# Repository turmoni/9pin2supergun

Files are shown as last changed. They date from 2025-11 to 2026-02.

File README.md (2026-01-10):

# 9pin2supergun
A project to read a CD32, Mega Drive/Genesis, or generic 9-pin gamepad and output each control to a separate pin for use with Neo Geos and/or Superguns.

I am personally using this code with a [Monster Joysticks CD32 joystick](https://monsterjoysticks.com/deluxe-cd32-retro-joystick-kit-classic) and a [Minigun Supergun](https://www.arcade-projects.com/threads/minigun-supergun-an-open-source-supergun.9408/).

There is a chance that there will be USB host support in the future, if using [the PCB](pcb/).

## Hardware

There are two expected paths to getting the hardware needed to use this; either build the PCB, or hook up a Pi Pico. For the most compact setup, but needing some more moderate to advanced soldering skills, build the PCB. For a potentially easier build, hook up a Pi Pico.

The PCB's files and some basic instructions can be found in [the pcb directory](pcb/). This isn't for people who are new to soldering - it has surface mount components, a dense layout, and the RP2040 package is very fine pitched.

Schematics and a reference PCB for hooking up a Pi Pico, along with details about the parts used, can be found in [the pico_reference directory](pico_reference/).

## Installation

If you don't want to customise anything, grab the latest uf2 file from [the releases page](https://github.com/turmoni/9pin2supergun/releases/) that matches your setup and install it to your board by holding down BOOTSEL when plugging it in to a PC, and then copying the file on to the storage device that appears. The PCB's BOOTSEL button is at the top-right. The options are:

* 9pin2supergun-**pcb**-v\*.uf2 - if you're using [the PCB I designed](pcb/)
* 9pin2supergun-**pico**-v\*.uf2 - if you're wiring up a Pico as per the schematic

Don't worry if you're missing optional components, the code shouldn't care.

## Usage

Once you've got a board programmed, using it is pretty much a case of setting the switch to the right position, plugging it in, and going! If you've fitted the LED, it will tell you which mode you're in:
* Red: Amiga CD32 mode
* Blue: Mega Drive/generic mode
* Yellow: Mega Drive/generic mode with the buttons swapped

The button mapping is as follows:

| Output | CD32[^1]  | Mega Drive/Genesis (6- or 3-button) | Generic 9-pin |
| --- | ---  | --- | --- |
| Up | Up | Up | Up |
| Down | Down | Down | Down |
| Left | Left | Left | Left |
| Right  | Right | Right | Right |
| 1 | G | A | 1 |
| 2 | Y | B | 2 |
| 3 | LS | C | N/A |
| 4 | R | X | N/A |
| 5 | B | Y | N/A |
| 6 | RS | Z | N/A |
| Start  | Pause | Start | 1 + 2 |
| Coin | Pause + G | Mode | N/A |

Of course, X, Y, Z, and Mode aren't present on a 3-button Mega Drive controller, so these buttons aren't available there.

Since the Mega Drive layout may be the opposite of what's wanted, you can press and hold mode for three seconds to swap ABC and XYZ.

If you don't want the 1+2 mapping for generic 9-pin controllers, set `MAP_GENERIC_AB_TO_START` to false and rebuild the code. If you don't want the Pause + Green mapping for CD32 controllers, or want it to be a different button combination, change `CD32_COIN_BITMASK` (there are comments in the code to explain its format). Since these are pretty niche, I'm not sure figuring out a runtime configuration option is worth it.

## Building the code

This project is based on the [rp2040 project template](https://github.com/rp-rs/rp2040-project-template), have a look there for details. You need a `rust` build environment and the project will build with Cargo.

If you're using a Pi Pico, rather than the PCB, pass the `--features pi_pico` flag to `cargo` when building to get the right pin assignments.

## Anything else

This polls at 125Hz for the CD32 - I don't know whether a real CD32 pad will be happy with this, but I don't see why it wouldn't. The timing for each polling burst is based on what I observed with my PAL Amiga 500+, so that should be fine, but it was only polling at 50Hz. Given how little time is spent polling compared to waiting even at 125Hz, though, I can't imagine what issues might arise.

The Mega Drive controller support polls at around 140Hz.

Current draw seems fairly low, hovering at around 20-25mA on the controllers I've tested it with. If you're worried, power it up via USB (not whilst connected to a 15-pin port!) and use a USB power meter to see how much it's drawing.

## Credits

Thanks to [Mathew Carr's PSCD32 Development Diary](https://www.mrdictionary.net/PSCD32/diary/2019_08_09.htm) for documenting how the CD32 protocol actually works, and to [the RetroSix Wiki's Mega Drive controller page](https://www.retrosix.wiki/controller-interface-sega-mega-drive) for documenting the Mega Drive bits.

[^1]: Single-letter CD32 buttons refer to the colour, LB and RB are the shoulder buttons

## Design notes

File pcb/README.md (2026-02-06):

# 9pin2supergun PCB

This is a PCB that contains all the components needed for a fully-functional hardware adapter to work with the [9pin2supergun project](/) in a compact package.

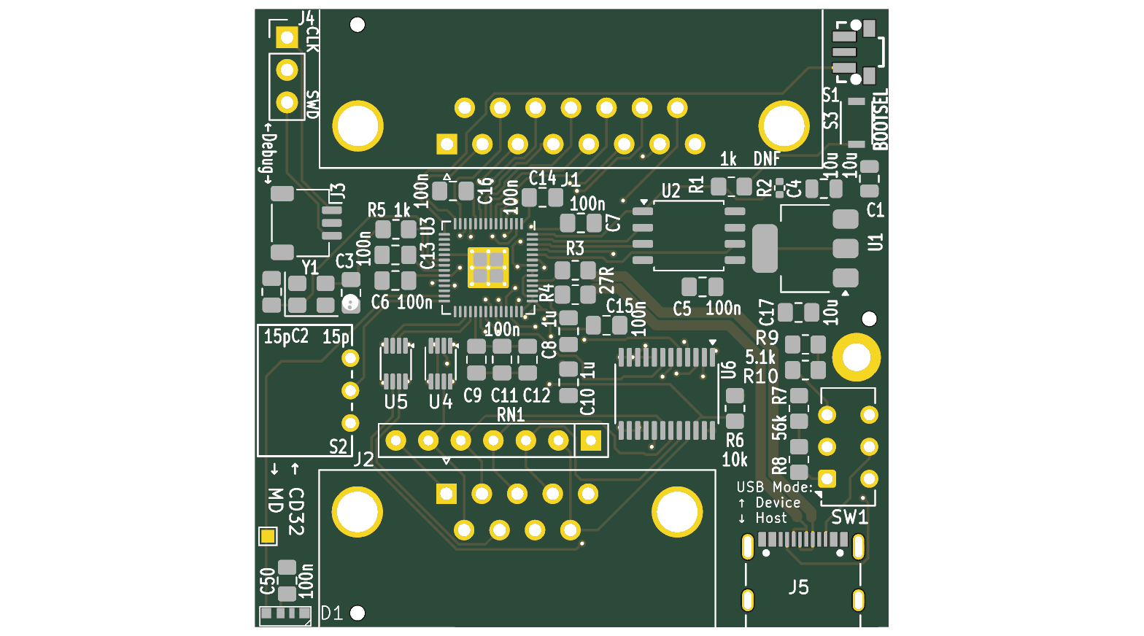
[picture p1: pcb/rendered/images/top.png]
The top of the PCB
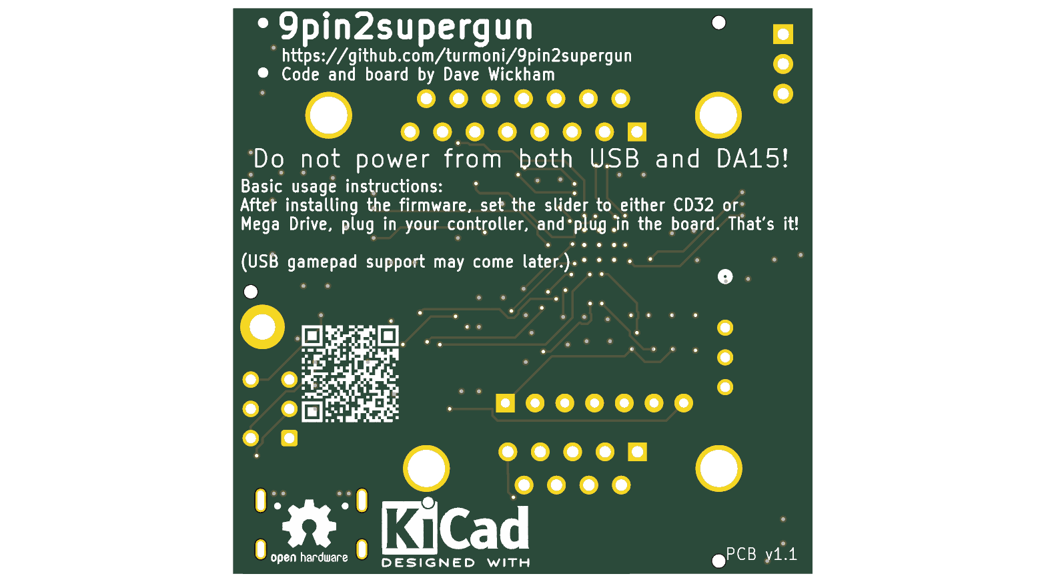
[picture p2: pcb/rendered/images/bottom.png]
The bottom of the PCB
 

## Building one

The KiCad project is in this directory, and for convenience each push gets rendered to [the `rendered` directory](/pcb/rendered/) as a PDF of the schematics, a set of gerber files, and a BOM as a CSV. You *should* be able to use [the gerber archive](/pcb/rendered/gbr.zip) to order boards directly, but for best results you should generate them yourself following your PCB fabricator's instructions (e.g. [for JLCPCB](https://jlcpcb.com/help/article/how-to-generate-gerber-and-drill-files-in-kicad-7)).

Unlike the related [Neo Geo Controller Tester](https://github.com/turmoni/neogeo_controller_tester), this is a moderately advanced soldering job. Don't be scared away from it if you're experienced with soldering (although you may need to learn some new techniques for fine pitched surface-mount components like the RP2040, and you probably want a hot plate, hot air gun, and solder paste), but if you're a complete beginner, this isn't for you.

The [BOM CSV](/pcb/rendered/bom.csv) has the list of parts, but I don't know how useful that is for importing elsewhere. I have [a DigiKey list](https://www.digikey.co.uk/en/mylists/list/U1CG00OTBV) that contains all the components that are needed, although at the time of writing, some of them are not available to order.

You may be able to get this fully/partially assembled from your PCB manufacturer - I didn't do this, so I can't comment, but there are only a few unusual components to manually spec and they are at least in LCSC (JLCPCB)'s database. If I end up doing this, I will probably replace U6 with more of the same type of shifter as U4 and U5 for cost reasons (one less reel to load).

When assembling, note that R2 is marked as DNF - if you're using the specified flash module, you shouldn't need to fit a resistor there. See [Hardware Design with RP2040](https://datasheets.raspberrypi.com/rp2040/hardware-design-with-rp2040.pdf) (PDF) for more information on this, since most of the support circuitry is adapted from that reference design.

## Things to note

SW1 switches between presenting itself as a USB device or a USB host, based on the resistors on the CC pins. This doesn't change anything with the software, and any cables other than Type C to Type C will be entirely unimpacted by this. Set it to Device (up) if you want to plug it into your PC, and Host (down) if you want to plug a gamepad into it. Since there's no code at the moment that uses host mode, it's safe to leave or hardcode it as a device for the moment (connect the middle pins of the switch to their respective top pins, and populate R9 and R10).

Do not power the board from more than one place, e.g. don't plug it into a supergun *and* a USB power source.

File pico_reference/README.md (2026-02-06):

# 9pin2supergun Reference Pico Design

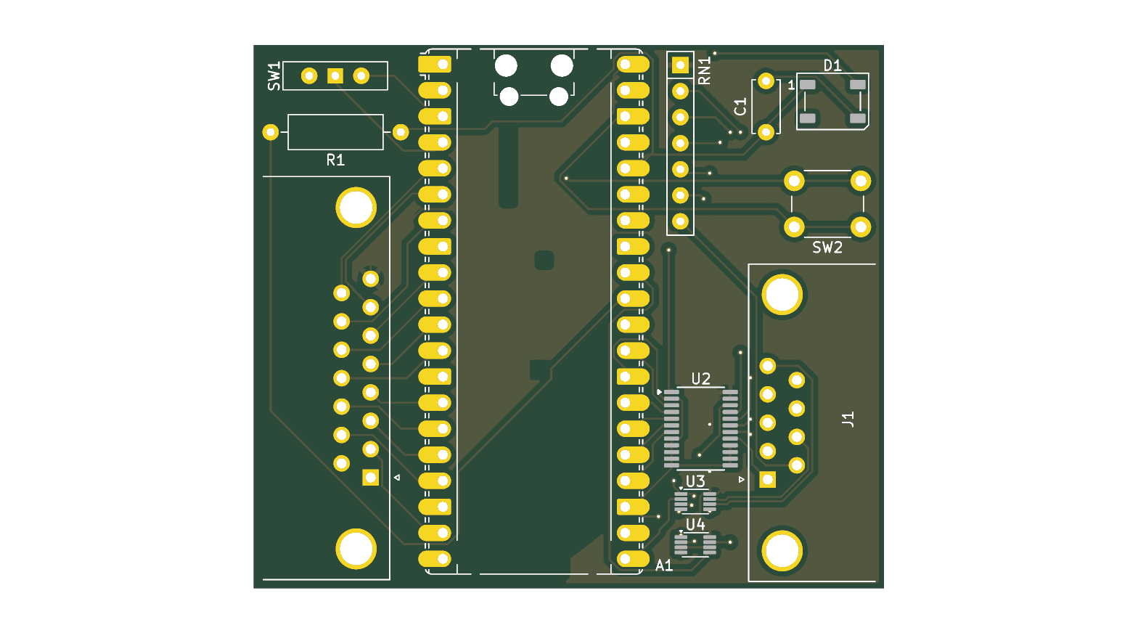
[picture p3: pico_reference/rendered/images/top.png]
The top of the reference PCB


This is a KiCad project for hooking up a Pi Pico to the appropriate hardware to get a fully working setup. As I see it, there are three main purposes for this project:

* To provide the schematic to use if wiring one up by hand, e.g. on a breadboard
* To give me PCBs based on the schematic so I can test that the schematic I've provided actually works, and is what the code expects
* To give a foundation for making new PCBs with different hardware than what I happened to have on hand

# Using the schematic

The schematic is hopefully fairly simple to understand, and can be found either by opening this project up in KiCad, or by looking at [the rendered PDF](rendered/sch.pdf).

# Building a PCB

First up: you probably don't want to use the PCB I've designed. The layout was literally done in about 20 minutes, with very little care given to routing traces to be neat, and it's designed to use the hardware I had on hand. If you want to use the components I've specified, I recommend instead using [the main PCB](../pcb), which is more compact and not *that* much harder to solder than what I have here.

If you do want to modify it, the KiCad project is in this directory.

For convenience each push gets rendered to [the `rendered` directory](rendered/) as a PDF of the schematics, a set of gerber files, and a BOM as a CSV, but again, you probably don't want to use the generated fabrication files as-is.

# Components and their explanations

If you're going to use your own components, the key things are:
 * U2 ([SN74LVC8T245](https://www.ti.com/product/SN74LVC8T245)) - this is just level shifting the input from the controller down to 3.3V. If you want to try out the Pico's 5V tolerance, you can omit this and RN1 if you want. Often the inputs will be either floating or GND, and so safe anyway, but I wouldn't totally rely on this being the case
 * U3/U4 ([SN74LVC2T45DCUR](https://www.ti.com/product/SN74LVC2T45)) - two-bit level shifters. U3 handles those that are always outputs, and U4 handles pin 6, which can either be an input or an output.
 * RN1 (10k resistor network) - pulling up the inputs from the controller port. Omit it if you're also omitting the level shifters
 * SW1 (SPDT switch) - the mode switch. Switches between Mega Drive (floating) and CD32 (tied to GND) modes. You can hardcode this if you're only using one type of controller
 * SW2 (standard push button) - not actually used, but might be helpful in the future
 * D1 (WS2812B LED) - indicates what mode you're in (including if the button rows are flipped in Mega Drive mode). Omit this if you don't care.

## More on level shifting

To recap, the level shifter U2 handles those inputs that are only ever inputs (pulled up to 5V). U3 handles both of the two outputs that can also be the +5V supply. U4 handles the one remaining pin that's either an input or an output depending on whether it's in CD32 or Mega Drive mode. There is nothing particularly special about any of these, they're just directional level shifters that can handle translating 3.3V to 5V or vice versa.
 
The connections to the DE9 connector are as follows:

| Pin | CD32 Function | CD32 Direction | Mega Drive Function | MD Direction |
| --- | --- | --- | --- | --- |
| 1 | Up | In | Up/Z | In |
| 2 | Down | In | Down/Y | In |
| 3 | Left | In | Left/X/GND | In |
| 4 | Right | In | Right/Mode/GND | In |
| 5 | Latch | Out | +5V | Out |
| 6 | Fire 1/Clock  | Out | B/A | In |
| 7 | +5V | Out | Select | Out |
| 8 | GND | N/A | GND | N/A |
| 9 | Fire 2/Data | In | C/Start | In |

As the table shows, the DE9 connector is a lot simpler if you're only targetting a single platform; for a CD32, you can permanently wire pin 7 to +5V, and pin 6 as an output, whereas with a Mega Drive controller you can wire pin 5 to +5V and pin 6 as an input. You may also be able to get away with not needing level shifters in this case, if you're willing to risk +5V into your Pico's GPIO pins, and your controller recognises 3.3V logic levels.

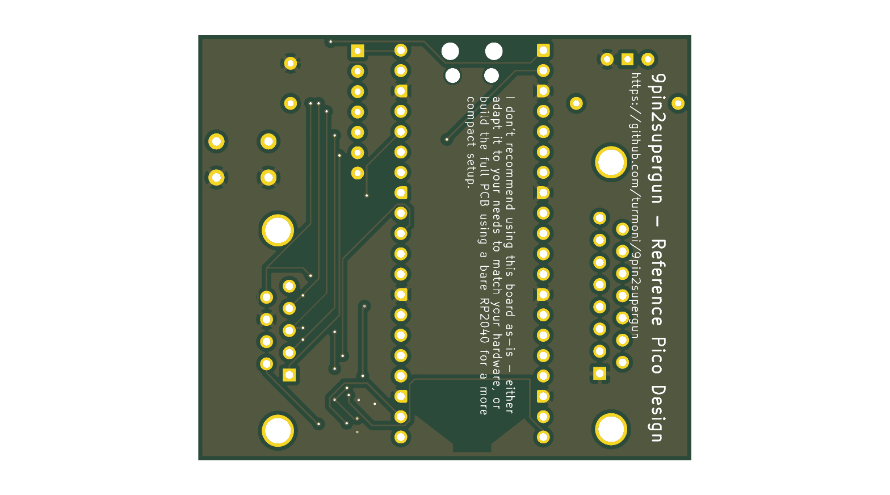
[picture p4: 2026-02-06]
pico_reference/rendered/images/bottom.png

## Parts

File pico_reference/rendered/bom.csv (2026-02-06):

Refs | Value | Footprint | Qty | DNP
A1 | RaspberryPi_Pico | Module:RaspberryPi_Pico_Common_Unspecified | 1
C1 | 100n | Capacitor_THT:C_Disc_D5.0mm_W2.5mm_P5.00mm | 1
D1 | WS2812B | LED_SMD:LED_WS2812B_PLCC4_5.0x5.0mm_P3.2mm | 1
J1 | Controller Input | Connector_Dsub:DSUB-9_Pins_Horizontal_P2.77x2.84mm_EdgePinOffset7.70mm_Housed_MountingHolesOffset9.12mm | 1
J2 | Output | Connector_Dsub:DSUB-15_Socket_Horizontal_P2.77x2.84mm_EdgePinOffset7.70mm_Housed_MountingHolesOffset9.12mm | 1
R1 | 10k | Resistor_THT:R_Axial_DIN0309_L9.0mm_D3.2mm_P12.70mm_Horizontal | 1
RN1 | R_Network06 | Resistor_THT:R_Array_SIP7 | 1
SW1 | SW_Wuerth_450301014042 | Button_Switch_THT:SW_Slide-03_Wuerth-WS-SLTV_10x2.5x6.4_P2.54mm | 1
SW2 | SW_Push | Button_Switch_THT:SW_PUSH_6mm | 1
U2 | SN74LVC8T245 | Package_SO:TSSOP-24_4.4x7.8mm_P0.65mm | 1
U3 | SN74LVC2T45DCUR | Package_SO:VSSOP-8_2.3x2mm_P0.5mm | 1
U4 | SN74LVC2T45DCUR | Package_SO:VSSOP-8_2.3x2mm_P0.5mm | 1

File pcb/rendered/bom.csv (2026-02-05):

Refs | Value | Footprint | Qty | DNP
C1 | 10u | Capacitor_SMD:C_0805_2012Metric | 1
C2 | 15p | Capacitor_SMD:C_0805_2012Metric_Pad1.18x1.45mm_HandSolder | 1
C3 | 15p | Capacitor_SMD:C_0805_2012Metric_Pad1.18x1.45mm_HandSolder | 1
C4 | 10u | Capacitor_SMD:C_0805_2012Metric | 1
C5 | 100n | Capacitor_SMD:C_0805_2012Metric_Pad1.18x1.45mm_HandSolder | 1
C6 | 100n | Capacitor_SMD:C_0805_2012Metric_Pad1.18x1.45mm_HandSolder | 1
C7 | 100n | Capacitor_SMD:C_0805_2012Metric_Pad1.18x1.45mm_HandSolder | 1
C8 | 1u | Capacitor_SMD:C_0805_2012Metric_Pad1.18x1.45mm_HandSolder | 1
C9 | 100n | Capacitor_SMD:C_0805_2012Metric_Pad1.18x1.45mm_HandSolder | 1
C10 | 1u | Capacitor_SMD:C_0805_2012Metric_Pad1.18x1.45mm_HandSolder | 1
C11 | 100n | Capacitor_SMD:C_0805_2012Metric_Pad1.18x1.45mm_HandSolder | 1
C12 | 100n | Capacitor_SMD:C_0805_2012Metric_Pad1.18x1.45mm_HandSolder | 1
C13 | 100n | Capacitor_SMD:C_0805_2012Metric_Pad1.18x1.45mm_HandSolder | 1
C14 | 100n | Capacitor_SMD:C_0805_2012Metric_Pad1.18x1.45mm_HandSolder | 1
C15 | 100n | Capacitor_SMD:C_0805_2012Metric_Pad1.18x1.45mm_HandSolder | 1
C16 | 100n | Capacitor_SMD:C_0805_2012Metric_Pad1.18x1.45mm_HandSolder | 1
C17 | 10u | Capacitor_SMD:C_0805_2012Metric_Pad1.18x1.45mm_HandSolder | 1
C50 | 100n | Capacitor_SMD:C_0805_2012Metric_Pad1.18x1.45mm_HandSolder | 1
D1 | SK6812B | 9pin2supergun:SK6812B | 1
J1 | Controller Output | Connector_Dsub:DSUB-15_Socket_Horizontal_P2.77x2.84mm_EdgePinOffset7.70mm_Housed_MountingHolesOffset9.12mm | 1
J2 | Controller Input | Connector_Dsub:DSUB-9_Pins_Horizontal_P2.77x2.84mm_EdgePinOffset7.70mm_Housed_MountingHolesOffset9.12mm | 1
J3 | Debug (JST SH) | Connector_JST:JST_SH_SM03B-SRSS-TB_1x03-1MP_P1.00mm_Horizontal | 1
J4 | Debug (2.54mm holes) | Connector_PinHeader_2.54mm:PinHeader_1x03_P2.54mm_Vertical | 1
J5 | UJ20-C-H-C-4-SMT-TR | 9pin2supergun:CUI_UJ20-C-H-C-4-SMT-TR | 1
R1 | 1k | Resistor_SMD:R_0805_2012Metric_Pad1.20x1.40mm_HandSolder | 1
R2 | DNF | Resistor_SMD:R_0402_1005Metric | 1
R3 | 27R | Resistor_SMD:R_0805_2012Metric_Pad1.20x1.40mm_HandSolder | 1
R4 | 27R | Resistor_SMD:R_0805_2012Metric_Pad1.20x1.40mm_HandSolder | 1
R5 | 1k | Resistor_SMD:R_0805_2012Metric_Pad1.20x1.40mm_HandSolder | 1
R6 | 10k | Resistor_SMD:R_0805_2012Metric_Pad1.20x1.40mm_HandSolder | 1
R7 | 56k | Resistor_SMD:R_0805_2012Metric_Pad1.20x1.40mm_HandSolder | 1
R8 | 56k | Resistor_SMD:R_0805_2012Metric_Pad1.20x1.40mm_HandSolder | 1
R9 | 5.1k | Resistor_SMD:R_0805_2012Metric_Pad1.20x1.40mm_HandSolder | 1
R10 | 5.1k | Resistor_SMD:R_0805_2012Metric_Pad1.20x1.40mm_HandSolder | 1
RN1 | 10k | Resistor_THT:R_Array_SIP7 | 1
S1 | 436333033816 | 9pin2supergun:436333033816 | 1
S2 | 09.10201.02 | footprints:SW3_09.10201.02_EAO | 1
S3 | R-667995 | 9pin2supergun:R-667995_MIT | 1
SW1 | SW_DPDT_x2 | Button_Switch_THT:SW_CK_JS202011CQN_DPDT_Straight | 1
U1 | NCP1117-3.3_SOT223 | Package_TO_SOT_SMD:SOT-223-3_TabPin2 | 1
U2 | W25Q128JVS | Package_SO:SOIC-8_5.23x5.23mm_P1.27mm | 1
U3 | RP2040 | MCU_RaspberryPi_and_Boards:RP2040-QFN-56 | 1
U4 | SN74LVC2T45DCUR | Package_SO:VSSOP-8_2.3x2mm_P0.5mm | 1
U5 | SN74LVC2T45DCUR | Package_SO:VSSOP-8_2.3x2mm_P0.5mm | 1
U6 | SN74LVC8T245 | Package_SO:TSSOP-24_4.4x7.8mm_P0.65mm | 1
Y1 | ABM8-272-T3 | Crystal:Crystal_SMD_3225-4Pin_3.2x2.5mm | 1

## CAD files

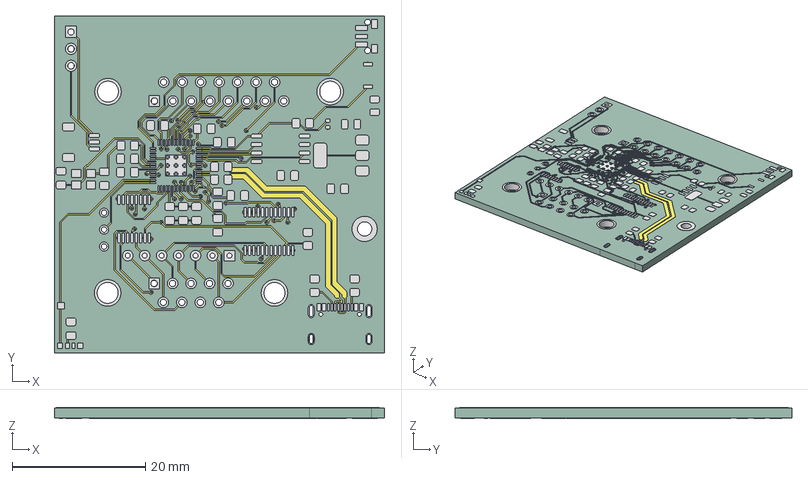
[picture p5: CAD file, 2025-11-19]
pcb/rendered/pcb.step
49.5 x 50.5 x 1.59 mm
9pin2supergun_copper
9pin2supergun_pad
9pin2supergun_via
9pin2supergun_PCB

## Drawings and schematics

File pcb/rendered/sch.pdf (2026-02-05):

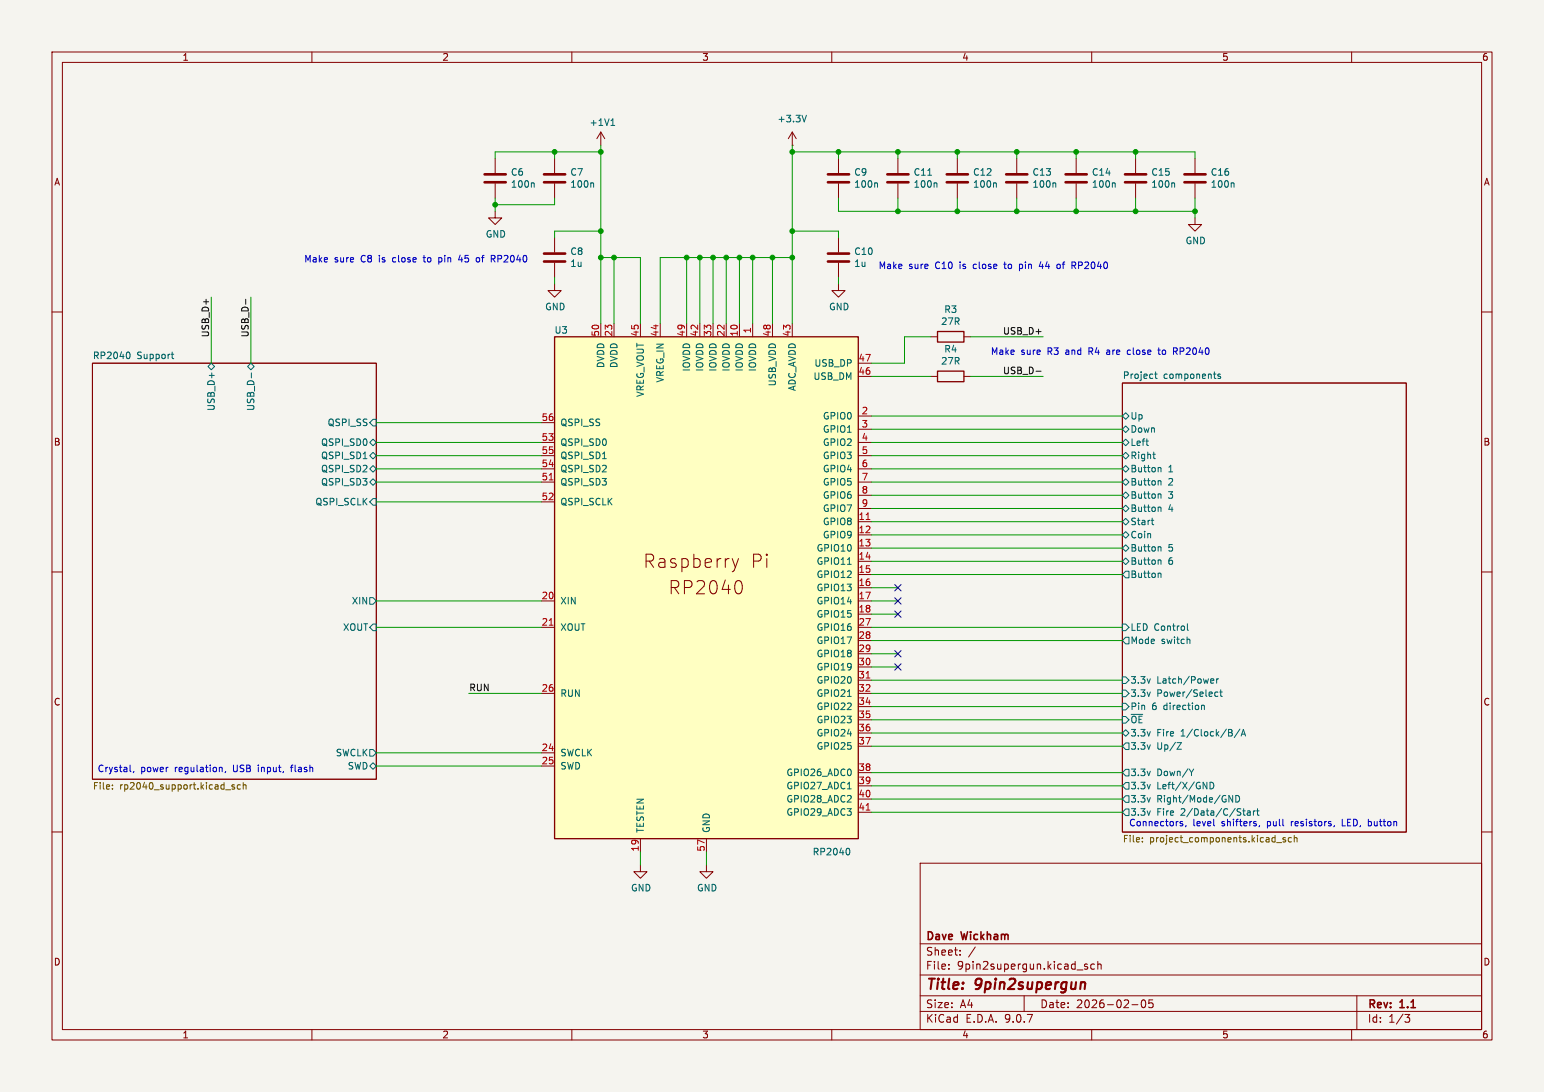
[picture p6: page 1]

LED Control Left Mode switch Pin 6 direction Right Start Up
3.3v Up/Z Button Button 1 Button 2 Button 3 Button 4 Button 5 Button 6 Coin Down

Project components File: project_components.kicad_sch SWCLK

3.3v Fire 2/Data/C/Start 3.3v Latch/Power 3.3v Left/X/GND
3.3v Power/Select 3.3v Right/Mode/GND

File: 9pin2supergun.kicad_sch Sheet: / Dave Wickham

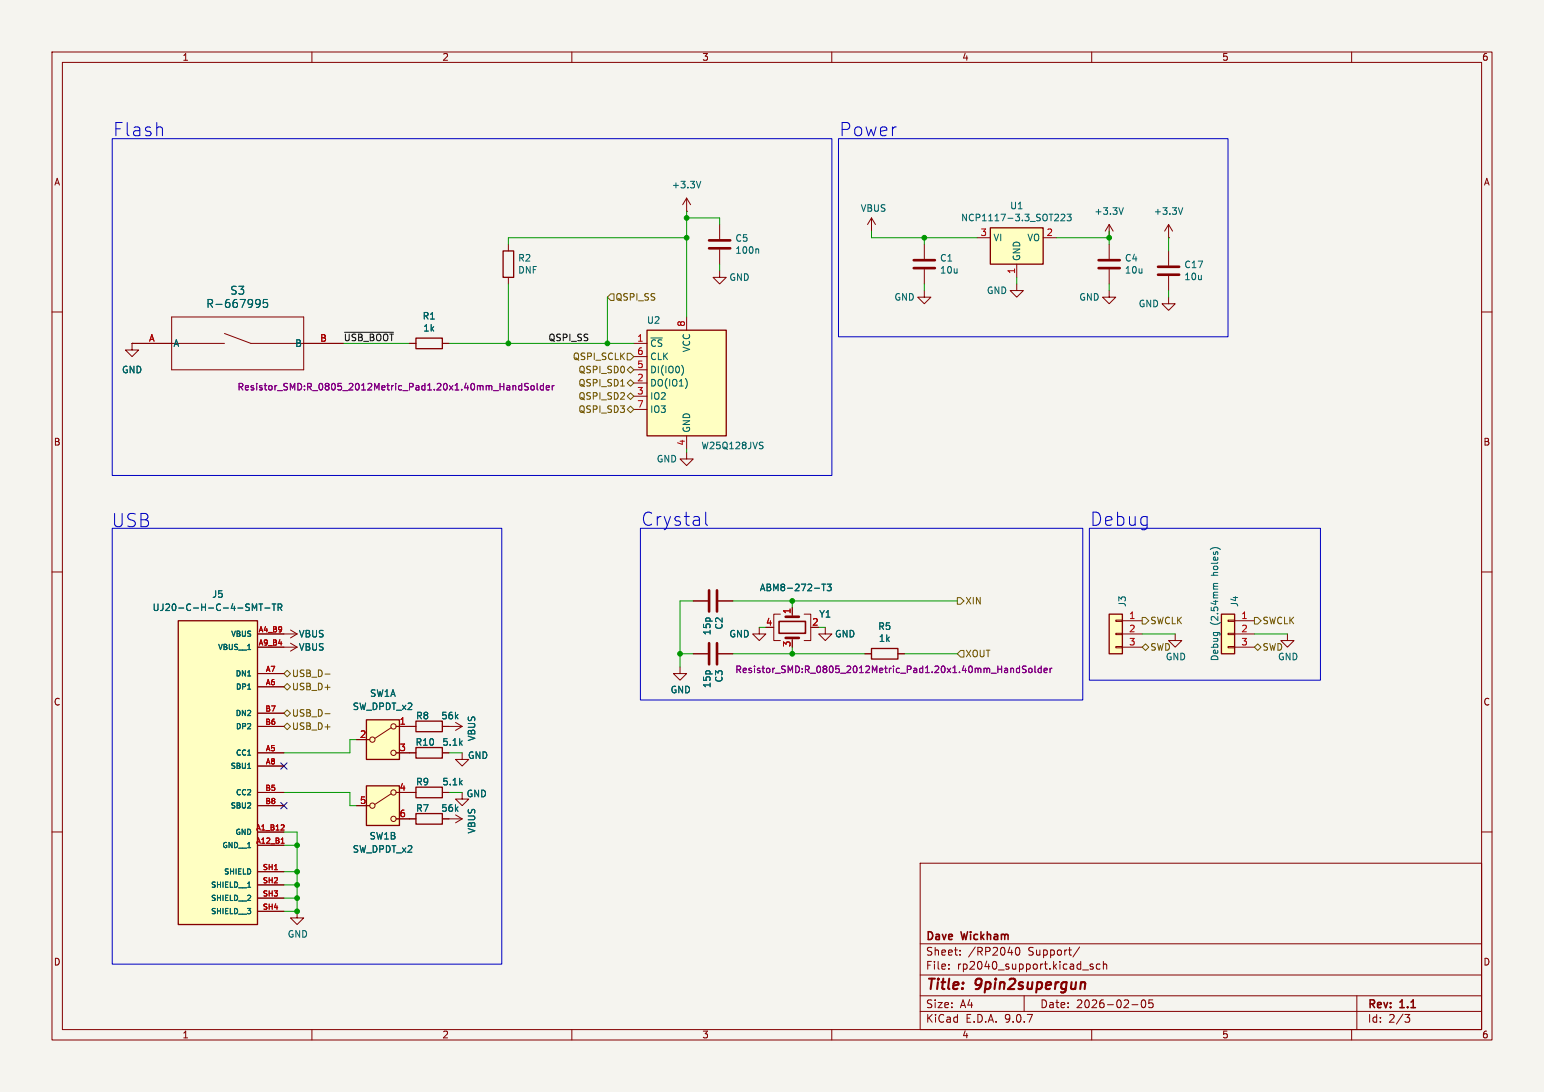
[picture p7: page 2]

~{CS} 1 CLK 6 DI(IO0) 5 DO(IO1) 2

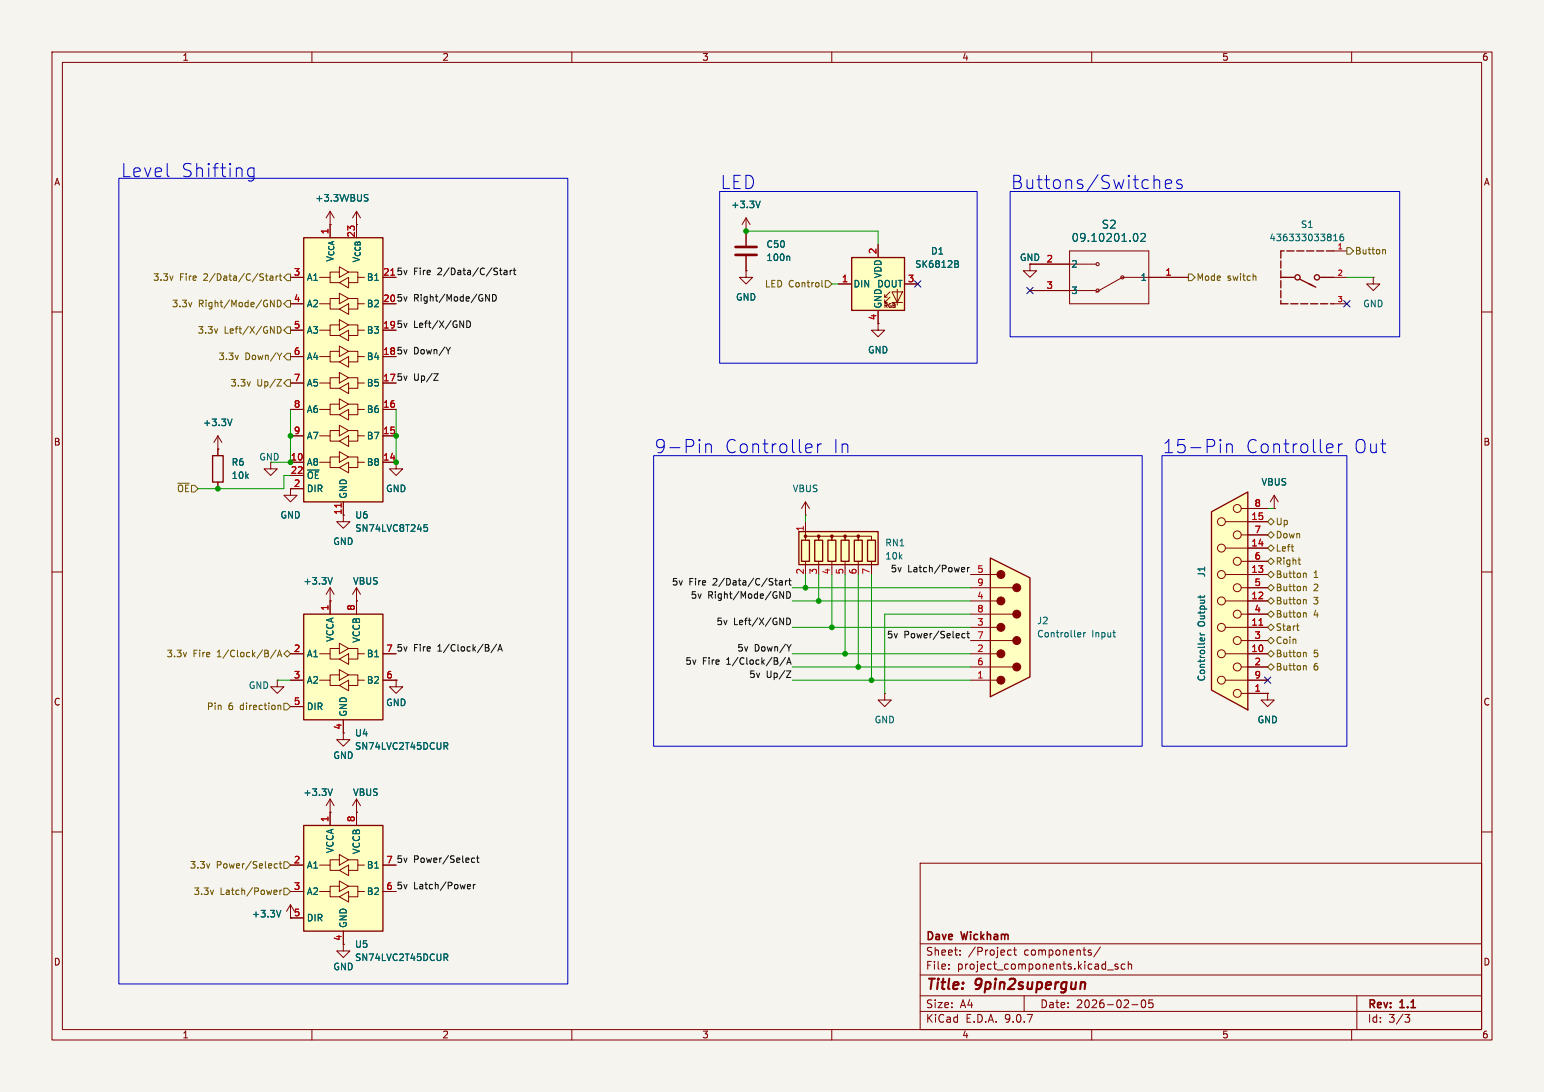
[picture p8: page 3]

Buttons/Switches Level Shifting
+3.3V VBUS GND
3.3v Fire 2/Data/C/Start 3.3v Up/Z Pin 6 direction

4 DOUT 3 D1 SK6812B GND GND GND

5v Fire 2/Data/C/Start 5v Down/Y

Left Mode switch LED Control

5v Latch/Power 5v Fire 1/Clock/B/A

5v Right/Mode/GND

5v Power/Select 5v Latch/Power

3.3v Latch/Power 3.3v Power/Select

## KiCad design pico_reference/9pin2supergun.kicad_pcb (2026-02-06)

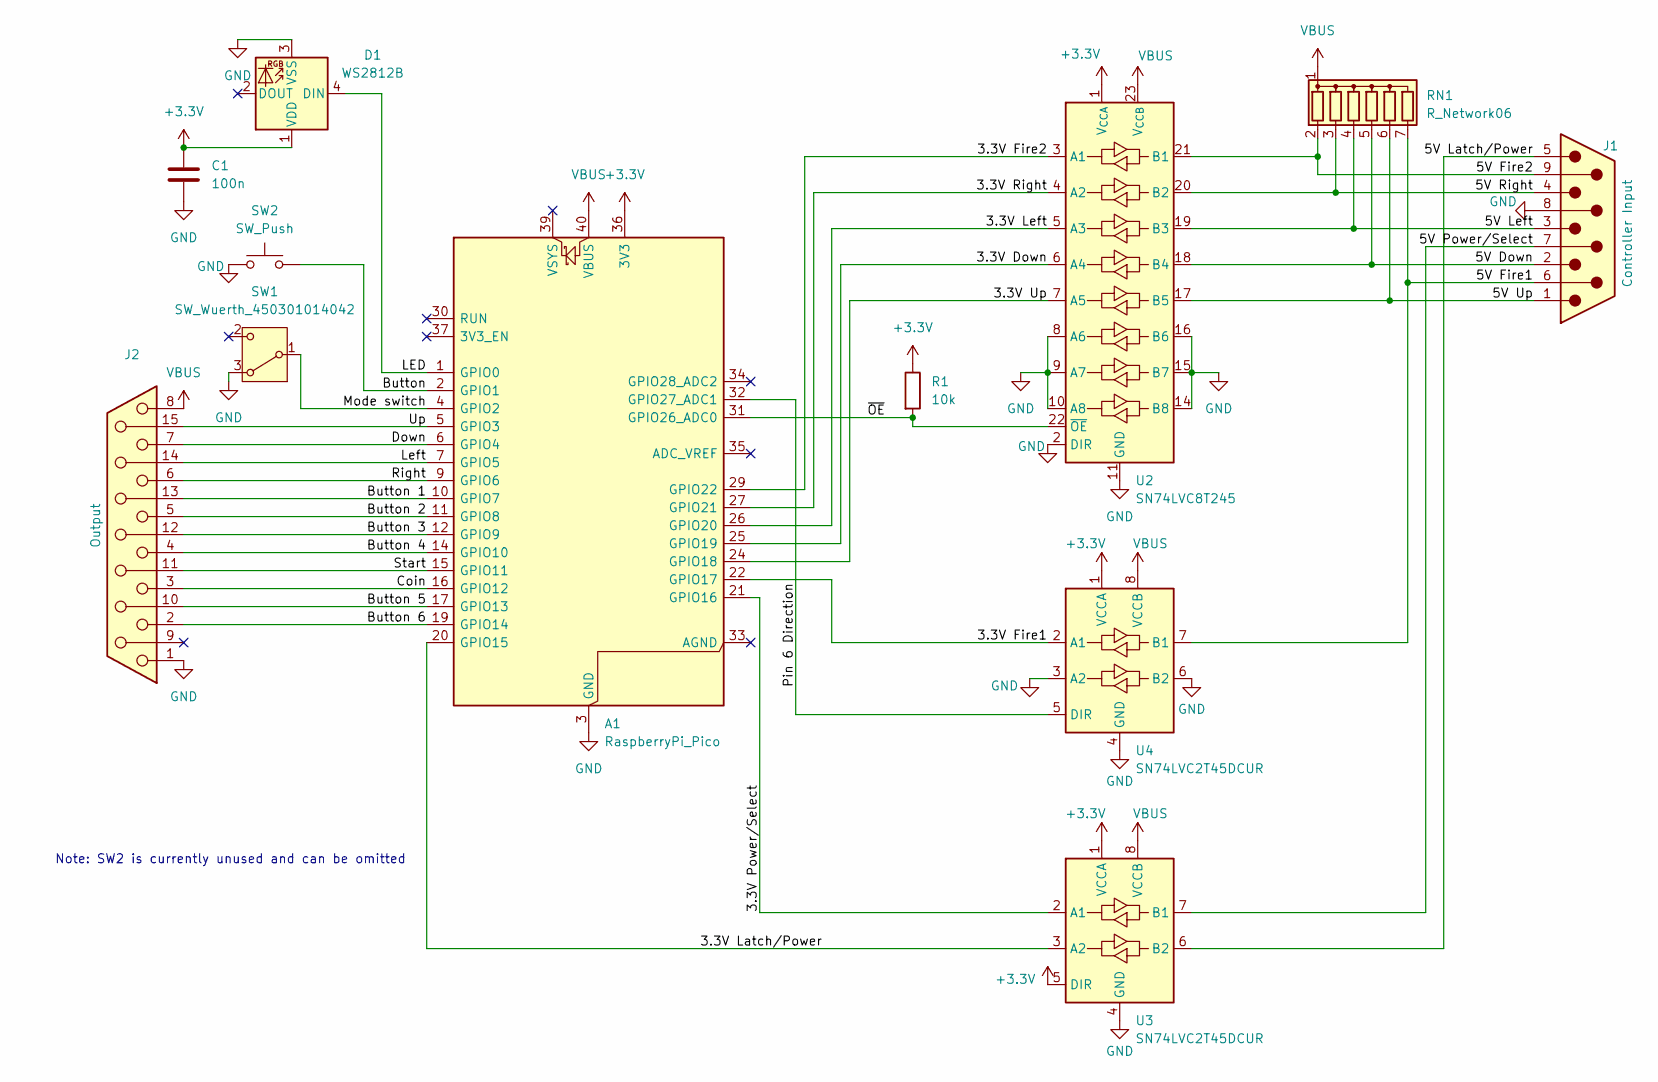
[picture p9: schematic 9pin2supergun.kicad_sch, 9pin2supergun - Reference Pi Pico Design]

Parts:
A1: RaspberryPi_Pico; RaspberryPi_Pico_Common_Unspecified
C1: 100n; C_Disc_D5.0mm_W2.5mm_P5.00mm
D1: WS2812B; LED_WS2812B_PLCC4_5.0x5.0mm_P3.2mm
J1: Controller Input; DSUB-9_Pins_Horizontal_P2.77x2.84mm_EdgePinOffset7.70mm_Hou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
J2: Output; DSUB-15_Socket_Horizontal_P2.77x2.84mm_EdgePinOffset7.70mm_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
R1: 10k; R_Axial_DIN0309_L9.0mm_D3.2mm_P12.70mm_Horizontal
RN1: R_Network06; R_Array_SIP7
SW1: SW_Wuerth_450301014042; SW_Slide-03_Wuerth-WS-SLTV_10x2.5x6.4_P2.54mm
SW2: SW_Push; SW_PUSH_6mm
U2: SN74LVC8T245; TSSOP-24_4.4x7.8mm_P0.65mm
U3, U4: SN74LVC2T45DCUR; VSSOP-8_2.3x2mm_P0.5mm

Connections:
+3.3V: A1.36 (3V3), C1.1, D1.1 (VDD), R1.1, U2.1 (V_{CCA}), U3.1 (VCCA), U3.5 (DIR), U4.1 (VCCA)
/3.3V Down: A1.25 (GPIO19), U2.6 (A4)
/3.3V Fire1: A1.22 (GPIO17), U4.2 (A1)
/3.3V Fire2: A1.29 (GPIO22), U2.3 (A1)
/3.3V Latch/Power: A1.20 (GPIO15), U3.3 (A2)
/3.3V Left: A1.26 (GPIO20), U2.5 (A3)
/3.3V Power/Select: A1.21 (GPIO16), U3.2 (A1)
/3.3V Right: A1.27 (GPIO21), U2.4 (A2)
/3.3V Up: A1.24 (GPIO18), U2.7 (A5)
/5V Down: J1.2, RN1.5 (R4), U2.18 (B4)
/5V Fire1: J1.6, RN1.7 (R6), U4.7 (B1)
/5V Fire2: J1.9, RN1.2 (R1), U2.21 (B1)
/5V Latch/Power: J1.5, U3.6 (B2)
/5V Left: J1.3, RN1.4 (R3), U2.19 (B3)
/5V Power/Select: J1.7, U3.7 (B1)
/5V Right: J1.4, RN1.3 (R2), U2.20 (B2)
/5V Up: J1.1, RN1.6 (R5), U2.17 (B5)
/Button: A1.2 (GPIO1), SW2.2
/Button 1: A1.10 (GPIO7), J2.13
/Button 2: A1.11 (GPIO8), J2.5
/Button 3: A1.12 (GPIO9), J2.12
/Button 4: A1.14 (GPIO10), J2.4
/Button 5: A1.17 (GPIO13), J2.10
/Button 6: A1.19 (GPIO14), J2.2
/Coin: A1.16 (GPIO12), J2.3
/Down: A1.6 (GPIO4), J2.7
/LED: A1.1 (GPIO0), D1.4 (DIN)
/Left: A1.7 (GPIO5), J2.14
/Mode switch: A1.4 (GPIO2), SW1.1 (B)
/Pin 6 Direction: A1.32 (GPIO27_ADC1), U4.5 (DIR)
/Right: A1.9 (GPIO6), J2.6
/Start: A1.15 (GPIO11), J2.11 (P111)
/Up: A1.5 (GPIO3), J2.15
/~OE: A1.31 (GPIO26_ADC0), R1.2, U2.22 (~OE)
GND: A1.3 (GND), A1.8 (GND), A1.13 (GND), A1.18 (GND), A1.23 (GND), A1.28 (GND), A1.38 (GND), C1.2, D1.3 (VSS), J1.8, J2.1, SW1.3 (A), SW2.1, U2.2 (DIR), U2.8 (A6), U2.9 (A7), U2.10 (A8), U2.11 (GND), U2.12 (GND), U2.13 (GND), U2.14 (B8), U2.15 (B7), U2.16 (B6), U3.4 (GND), U4.3 (A2), U4.4 (GND), U4.6 (B2)
VBUS: A1.40 (VBUS), J2.8, RN1.1 (common), U2.23 (V_{CCB}), U2.24 (V_{CCB}), U3.8 (VCCB), U4.8 (VCCB)

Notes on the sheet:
Note: SW2 is currently unused and can be omitted

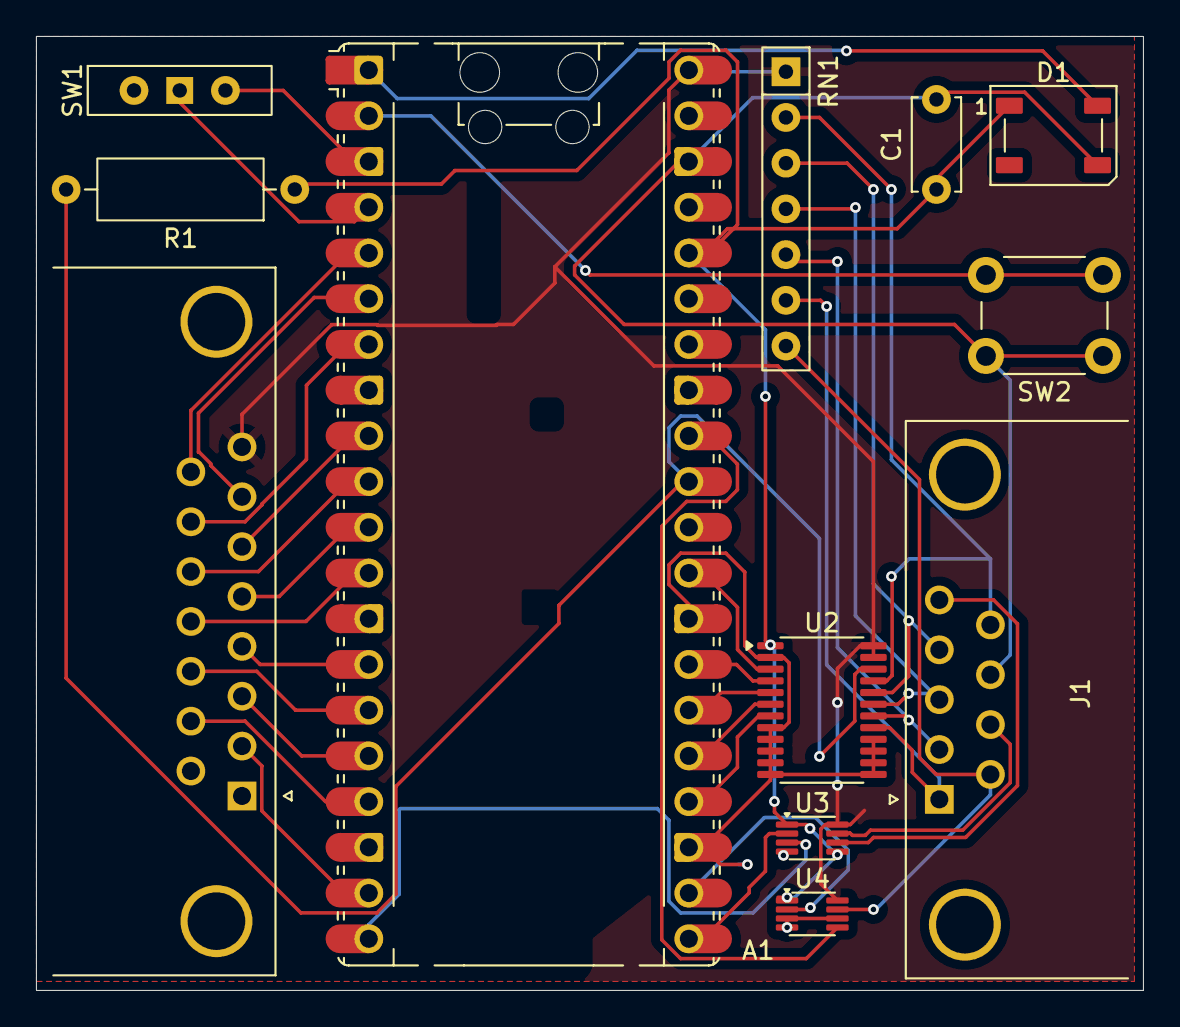
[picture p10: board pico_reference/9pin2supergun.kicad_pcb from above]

Board: 2 copper layers, 61.5 x 53.0 mm, 12 parts (0 on the bottom side), 36 nets.

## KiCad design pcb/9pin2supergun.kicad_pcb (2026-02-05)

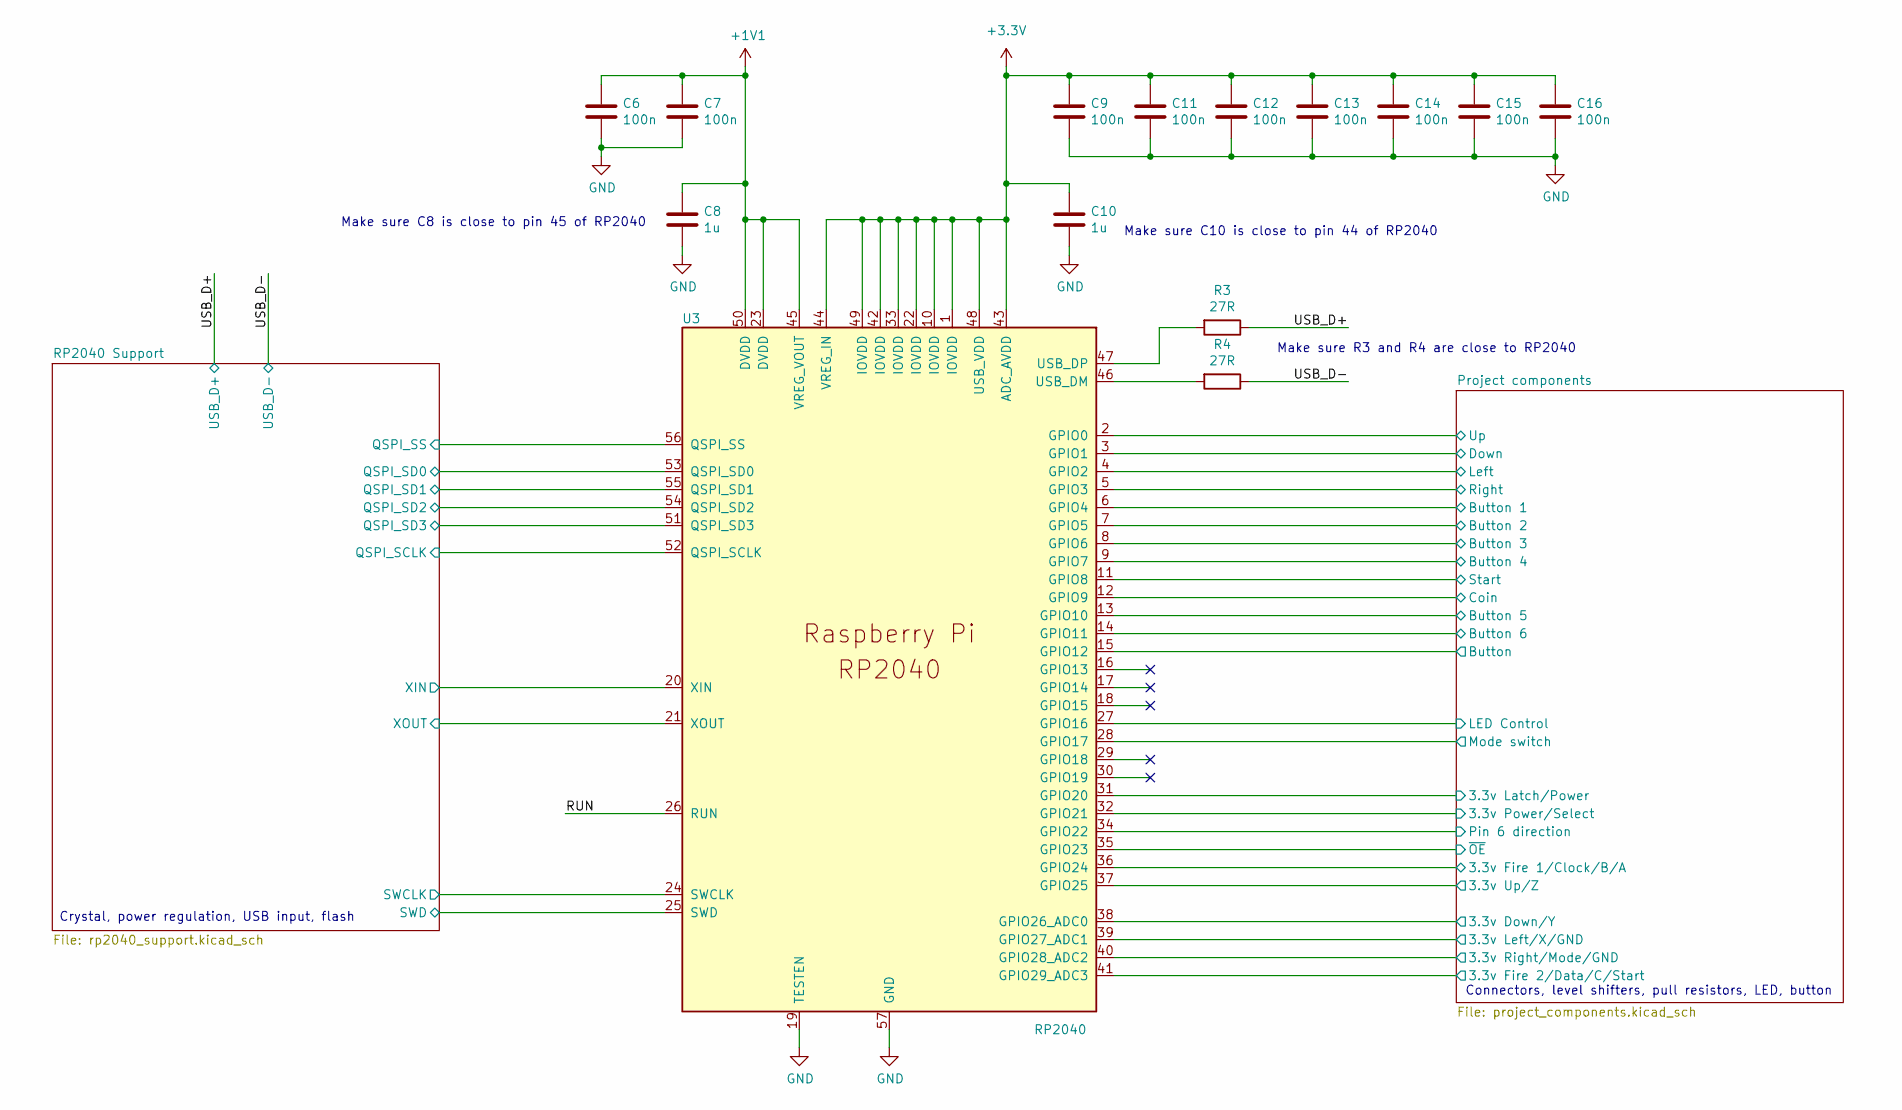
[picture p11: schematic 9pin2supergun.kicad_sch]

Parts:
C6, C7, C9, C11, C12, C13, C14, C15, C16: 100n; C_0805_2012Metric_Pad1.18x1.45mm_HandSolder
C8, C10: 1u; C_0805_2012Metric_Pad1.18x1.45mm_HandSolder
R3, R4: 27R; R_0805_2012Metric_Pad1.20x1.40mm_HandSolder
U3: RP2040; RP2040-QFN-56

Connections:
+1V1: C6.1, C7.1, C8.1, U3.23 (DVDD), U3.45 (VREG_VOUT), U3.50 (DVDD)
+3.3V: C9.1, C10.1, C11.1, C12.1, C13.1, C14.1, C15.1, C16.1, U3.1 (IOVDD), U3.10 (IOVDD), U3.22 (IOVDD), U3.33 (IOVDD), U3.42 (IOVDD), U3.43 (ADC_AVDD), U3.44 (VREG_IN), U3.48 (USB_VDD), U3.49 (IOVDD); also elsewhere on the board
/Project components/3.3v Down/Y: U3.38 (GPIO26_ADC0); also elsewhere on the board
/Project components/3.3v Fire 1/Clock/B/A: U3.36 (GPIO24); also elsewhere on the board
/Project components/3.3v Fire 2/Data/C/Start: U3.41 (GPIO29_ADC3); also elsewhere on the board
/Project components/3.3v Latch/Power: U3.31 (GPIO20); also elsewhere on the board
/Project components/3.3v Left/X/GND: U3.39 (GPIO27_ADC1); also elsewhere on the board
/Project components/3.3v Power/Select: U3.32 (GPIO21); also elsewhere on the board
/Project components/3.3v Right/Mode/GND: U3.40 (GPIO28_ADC2); also elsewhere on the board
/Project components/3.3v Up/Z: U3.37 (GPIO25); also elsewhere on the board
/Project components/Button: U3.15 (GPIO12); also elsewhere on the board
/Project components/Button 1: U3.6 (GPIO4); also elsewhere on the board
/Project components/Button 2: U3.7 (GPIO5); also elsewhere on the board
/Project components/Button 3: U3.8 (GPIO6); also elsewhere on the board
/Project components/Button 4: U3.9 (GPIO7); also elsewhere on the board
/Project components/Button 5: U3.13 (GPIO10); also elsewhere on the board
/Project components/Button 6: U3.14 (GPIO11); also elsewhere on the board
/Project components/Coin: U3.12 (GPIO9); also elsewhere on the board
/Project components/Down: U3.3 (GPIO1); also elsewhere on the board
/Project components/LED Control: U3.27 (GPIO16); also elsewhere on the board
/Project components/Left: U3.4 (GPIO2); also elsewhere on the board
/Project components/Mode switch: U3.28 (GPIO17); also elsewhere on the board
/Project components/Pin 6 direction: U3.34 (GPIO22); also elsewhere on the board
/Project components/Right: U3.5 (GPIO3); also elsewhere on the board
/Project components/Start: U3.11 (GPIO8); also elsewhere on the board
/Project components/Up: U3.2 (GPIO0); also elsewhere on the board
/Project components/~OE: U3.35 (GPIO23); also elsewhere on the board
/RP2040 Support/QSPI_SCLK: U3.52 (QSPI_SCLK); also elsewhere on the board
/RP2040 Support/QSPI_SD0: U3.53 (QSPI_SD0); also elsewhere on the board
/RP2040 Support/QSPI_SD1: U3.55 (QSPI_SD1); also elsewhere on the board
/RP2040 Support/QSPI_SD2: U3.54 (QSPI_SD2); also elsewhere on the board
/RP2040 Support/QSPI_SD3: U3.51 (QSPI_SD3); also elsewhere on the board
/RP2040 Support/QSPI_SS: U3.56 (QSPI_SS); also elsewhere on the board
/RP2040 Support/SWCLK: U3.24 (SWCLK); also elsewhere on the board
/RP2040 Support/SWD: U3.25 (SWD); also elsewhere on the board
/RP2040 Support/XIN: U3.20 (XIN); also elsewhere on the board
/RP2040 Support/XOUT: U3.21 (XOUT); also elsewhere on the board
/RUN: U3.26 (RUN)
/USB_D+: R3.1; also elsewhere on the board
/USB_D-: R4.1; also elsewhere on the board
GND: C6.2, C7.2, C8.2, C9.2, C10.2, C11.2, C12.2, C13.2, C14.2, C15.2, C16.2, U3.19 (TESTEN), U3.57 (GND); also elsewhere on the board
unnamed: R4.2, U3.46 (USB_DM)
unnamed: R3.2, U3.47 (USB_DP)

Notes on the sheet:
Crystal, power regulation, USB input, flash
Make sure C8 is close to pin 45 of RP2040
Connectors, level shifters, pull resistors, LED, button
Make sure C10 is close to pin 44 of RP2040
Make sure R3 and R4 are close to RP2040

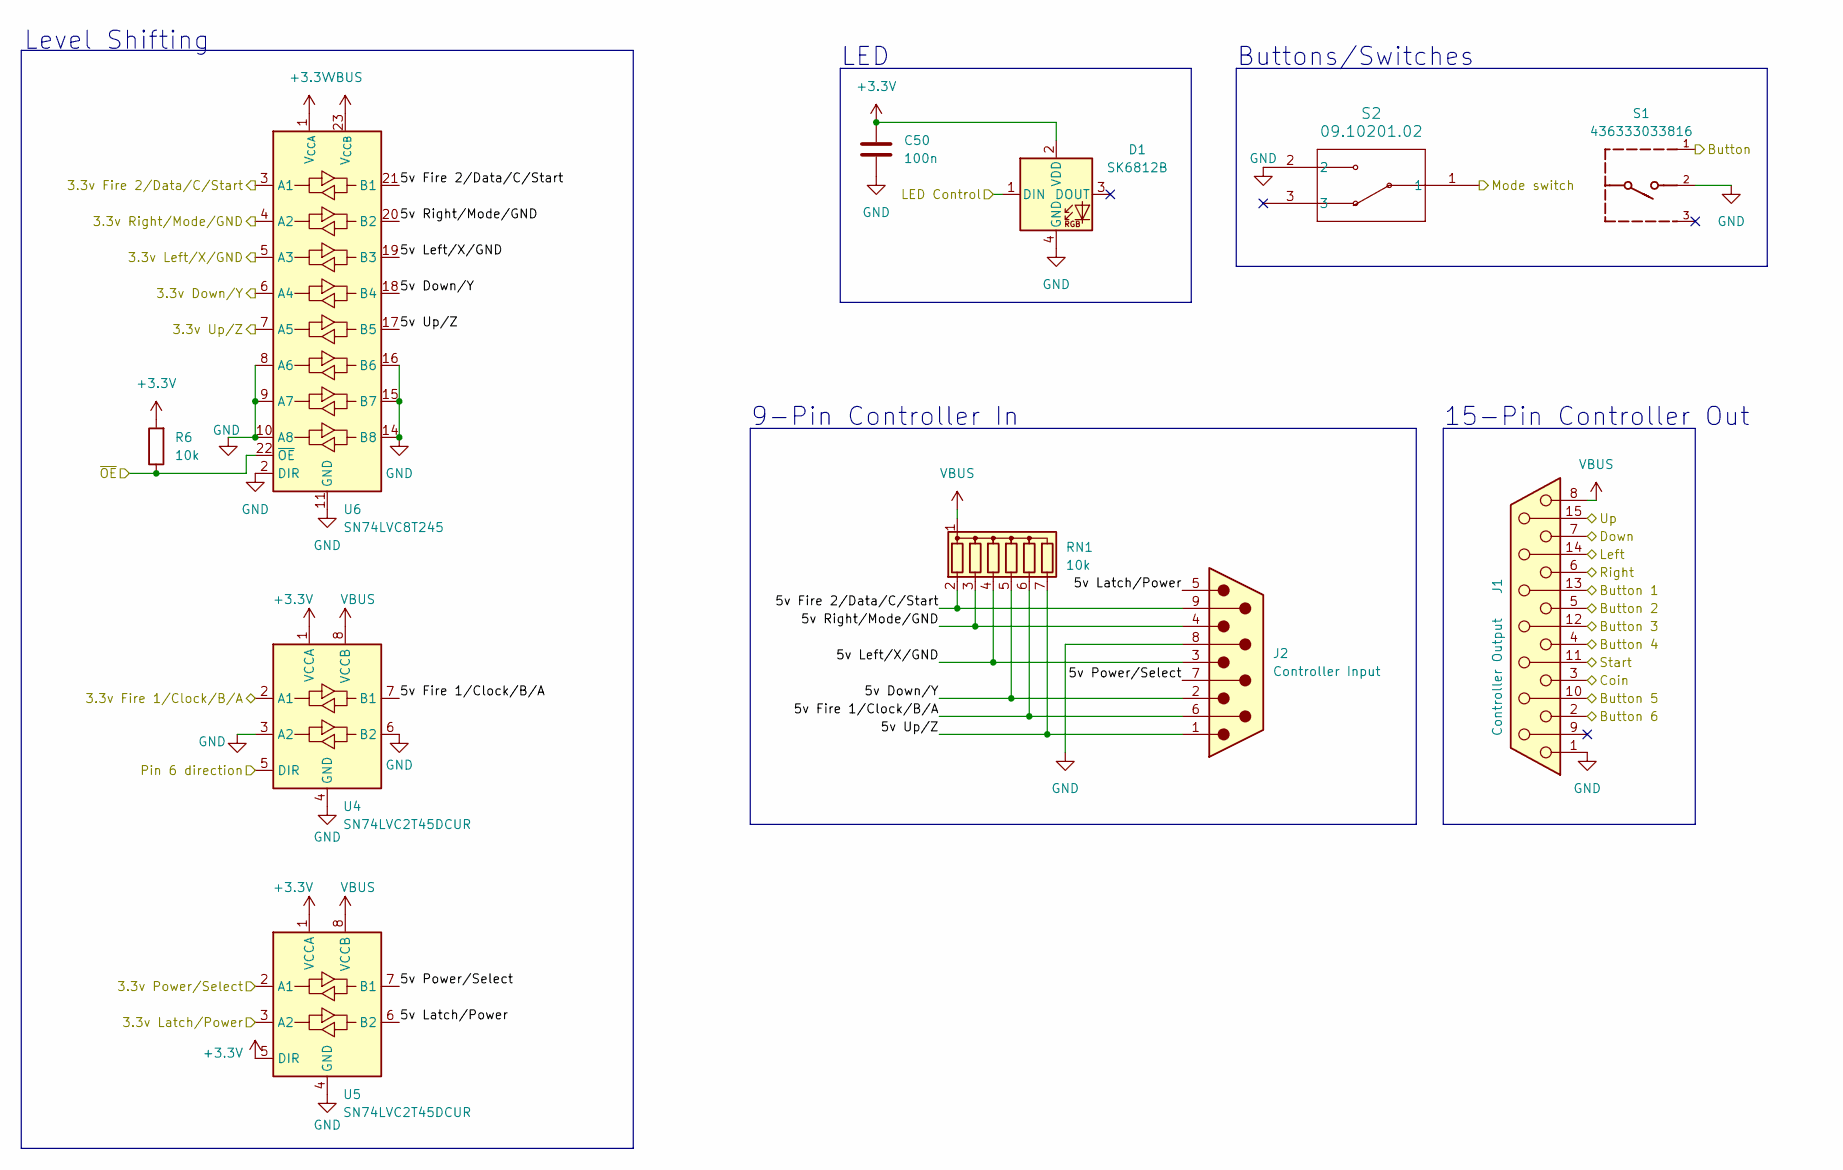
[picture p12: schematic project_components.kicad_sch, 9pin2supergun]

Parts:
C50: 100n; C_0805_2012Metric_Pad1.18x1.45mm_HandSolder
D1: SK6812B
J1: Controller Output; DSUB-15_Socket_Horizontal_P2.77x2.84mm_EdgePinOffset7.70mm_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
J2: Controller Input; DSUB-9_Pins_Horizontal_P2.77x2.84mm_EdgePinOffset7.70mm_Hou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
R6: 10k; R_0805_2012Metric_Pad1.20x1.40mm_HandSolder
RN1: 10k; R_Array_SIP7
S1: 436333033816; PART-NUMBER 436333033816
S2: 09.10201.02; SW3_09.10201.02_EAO
U4, U5: SN74LVC2T45DCUR; VSSOP-8_2.3x2mm_P0.5mm
U6: SN74LVC8T245; TSSOP-24_4.4x7.8mm_P0.65mm

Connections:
+3.3V: C50.1, D1.2 (VDD), R6.2, U4.1 (VCCA), U5.1 (VCCA), U5.5 (DIR), U6.1 (V_{CCA}); also elsewhere on the board
/Project components/3.3v Down/Y: U6.6 (A4); also elsewhere on the board
/Project components/3.3v Fire 1/Clock/B/A: U4.2 (A1); also elsewhere on the board
/Project components/3.3v Fire 2/Data/C/Start: U6.3 (A1); also elsewhere on the board
/Project components/3.3v Latch/Power: U5.3 (A2); also elsewhere on the board
/Project components/3.3v Left/X/GND: U6.5 (A3); also elsewhere on the board
/Project components/3.3v Power/Select: U5.2 (A1); also elsewhere on the board
/Project components/3.3v Right/Mode/GND: U6.4 (A2); also elsewhere on the board
/Project components/3.3v Up/Z: U6.7 (A5); also elsewhere on the board
/Project components/5v Down/Y: J2.2 (Down/Y), RN1.5 (R4), U6.18 (B4)
/Project components/5v Fire 1/Clock/B/A: J2.6 (Fire_1/Clock/B/A), RN1.6 (R5), U4.7 (B1)
/Project components/5v Fire 2/Data/C/Start: J2.9 (Fire_2/Data/C/Start), RN1.2 (R1), U6.21 (B1)
/Project components/5v Latch/Power: J2.5 (Latch/+5V), U5.6 (B2)
/Project components/5v Left/X/GND: J2.3 (Left/X/Gnd), RN1.4 (R3), U6.19 (B3)
/Project components/5v Power/Select: J2.7 (+5V/Select), U5.7 (B1)
/Project components/5v Right/Mode/GND: J2.4 (Right/Mode/Gnd), RN1.3 (R2), U6.20 (B2)
/Project components/5v Up/Z: J2.1 (Up/Z), RN1.7 (R6), U6.17 (B5)
/Project components/Button: S1.1; also elsewhere on the board
/Project components/Button 1: J1.13; also elsewhere on the board
/Project components/Button 2: J1.5; also elsewhere on the board
/Project components/Button 3: J1.12; also elsewhere on the board
/Project components/Button 4: J1.4; also elsewhere on the board
/Project components/Button 5: J1.10; also elsewhere on the board
/Project components/Button 6: J1.2; also elsewhere on the board
/Project components/Coin: J1.3; also elsewhere on the board
/Project components/Down: J1.7; also elsewhere on the board
/Project components/LED Control: D1.1 (DIN); also elsewhere on the board
/Project components/Left: J1.14; also elsewhere on the board
/Project components/Mode switch: S2.1; also elsewhere on the board
/Project components/Pin 6 direction: U4.5 (DIR); also elsewhere on the board
/Project components/Right: J1.6; also elsewhere on the board
/Project components/Start: J1.11 (P111); also elsewhere on the board
/Project components/Up: J1.15; also elsewhere on the board
/Project components/~OE: R6.1, U6.22 (~OE); also elsewhere on the board
GND: C50.2, D1.4 (GND), J1.1, J2.8 (GND), S1.2, S2.2, U4.3 (A2), U4.4 (GND), U4.6 (B2), U5.4 (GND), U6.2 (DIR), U6.8 (A6), U6.9 (A7), U6.10 (A8), U6.11 (GND), U6.12 (GND), U6.13 (GND), U6.14 (B8), U6.15 (B7), U6.16 (B6); also elsewhere on the board
VBUS: J1.8, RN1.1 (common), U4.8 (VCCB), U5.8 (VCCB), U6.23 (V_{CCB}), U6.24 (V_{CCB}); also elsewhere on the board

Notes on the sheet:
15-Pin Controller Out
LED
9-Pin Controller In
Buttons/Switches
Level Shifting

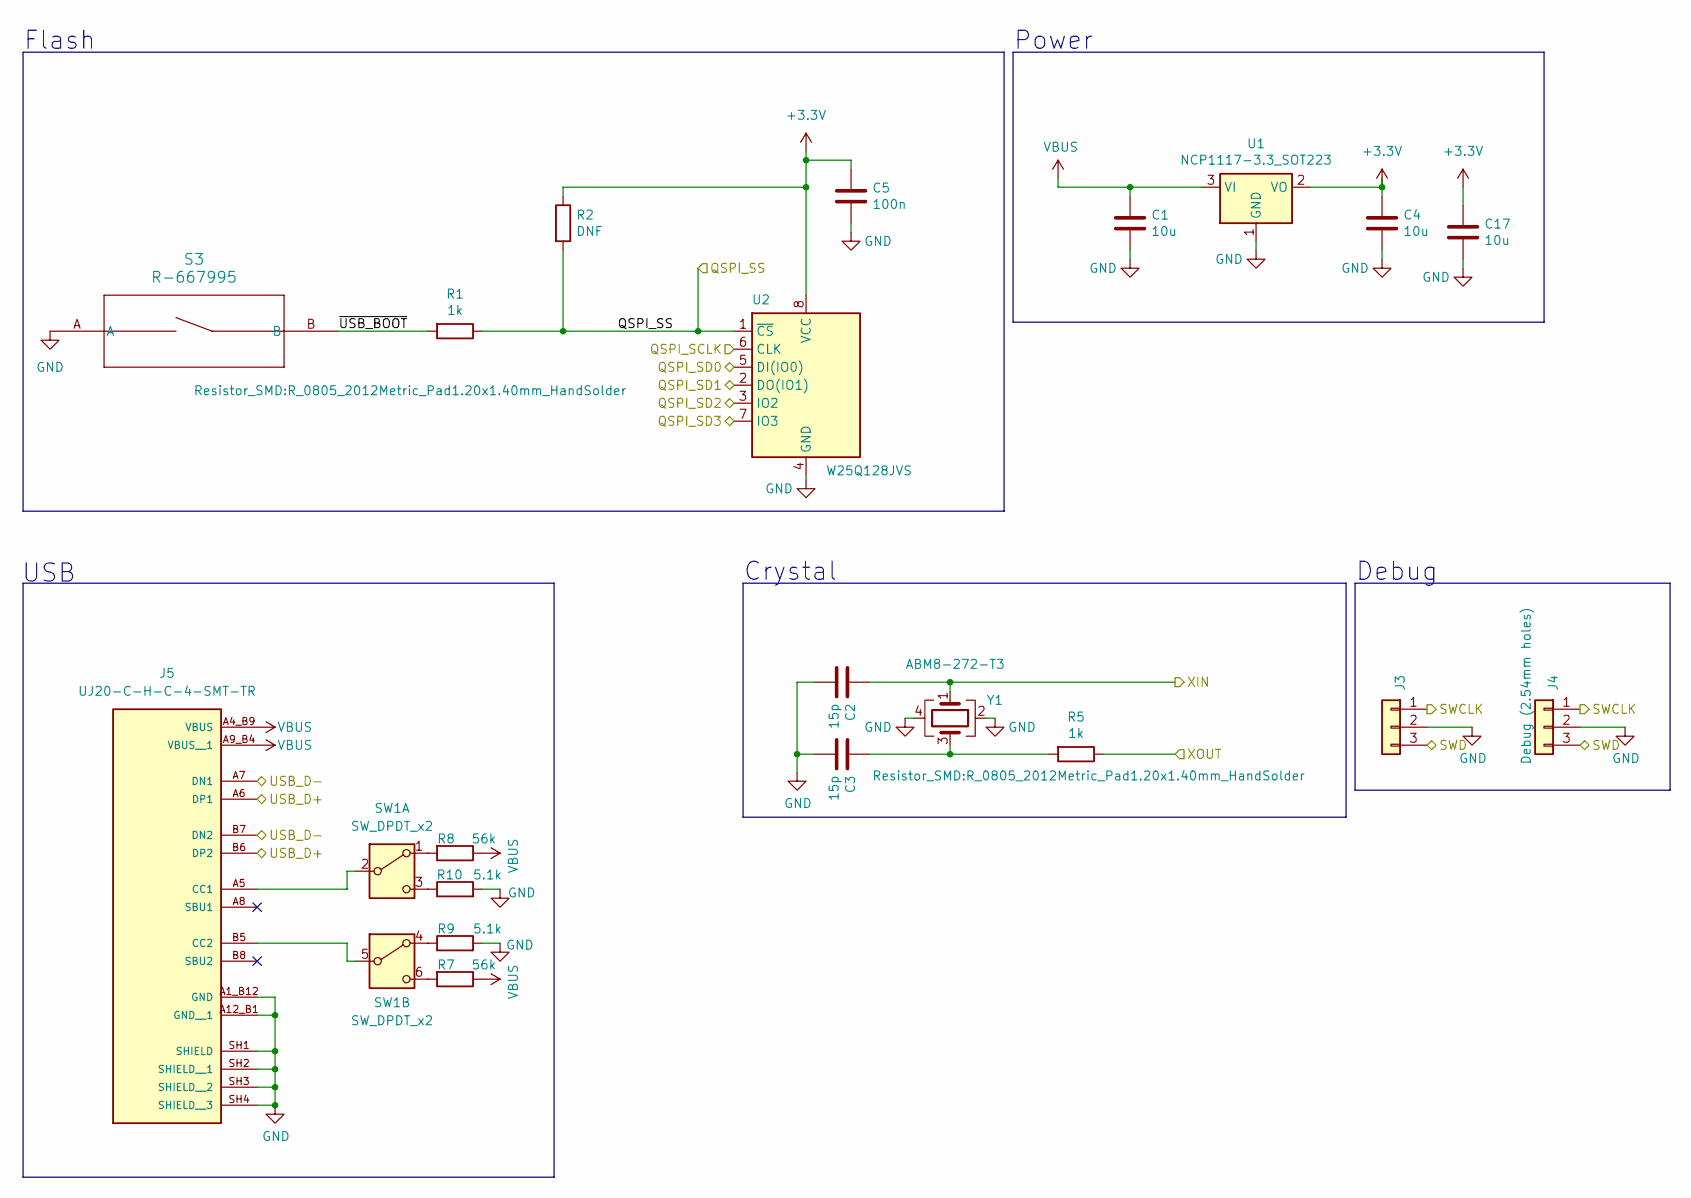
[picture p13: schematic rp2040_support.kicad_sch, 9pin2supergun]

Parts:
C1, C4: 10u; C_0805_2012Metric
C2, C3: 15p; C_0805_2012Metric_Pad1.18x1.45mm_HandSolder
C5: 100n; C_0805_2012Metric_Pad1.18x1.45mm_HandSolder
C17: 10u; C_0805_2012Metric_Pad1.18x1.45mm_HandSolder
J3: Debug (JST SH); JST_SH_SM03B-SRSS-TB_1x03-1MP_P1.00mm_Horizontal
J4: Debug (2.54mm holes); PinHeader_1x03_P2.54mm_Vertical
J5: UJ20-C-H-C-4-SMT-TR; CUI_UJ20-C-H-C-4-SMT-TR; PARTREV 1.0
R1, R5: 1k; R_0805_2012Metric_Pad1.20x1.40mm_HandSolder
R2: DNF; R_0402_1005Metric
R7, R8: 56k; R_0805_2012Metric_Pad1.20x1.40mm_HandSolder
R9, R10: 5.1k; R_0805_2012Metric_Pad1.20x1.40mm_HandSolder
S3: R-667995; R-667995_MIT
SW1: SW_DPDT_x2; SW_CK_JS202011CQN_DPDT_Straight
U1: NCP1117-3.3_SOT223; SOT-223-3_TabPin2
U2: W25Q128JVS; SOIC-8_5.23x5.23mm_P1.27mm
Y1: ABM8-272-T3; Crystal_SMD_3225-4Pin_3.2x2.5mm

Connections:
+3.3V: C4.1, C5.1, C17.1, R2.1, U1.2 (VO), U2.8 (VCC); also elsewhere on the board
/RP2040 Support/QSPI_SCLK: U2.6 (CLK); also elsewhere on the board
/RP2040 Support/QSPI_SD0: U2.5 (DI(IO0)); also elsewhere on the board
/RP2040 Support/QSPI_SD1: U2.2 (DO(IO1)); also elsewhere on the board
/RP2040 Support/QSPI_SD2: U2.3 (IO2); also elsewhere on the board
/RP2040 Support/QSPI_SD3: U2.7 (IO3); also elsewhere on the board
/RP2040 Support/QSPI_SS: R1.1, R2.2, U2.1 (~CS); also elsewhere on the board
/RP2040 Support/SWCLK: J3.1, J4.1; also elsewhere on the board
/RP2040 Support/SWD: J3.3, J4.3; also elsewhere on the board
/RP2040 Support/XIN: C2.1, Y1.1; also elsewhere on the board
/RP2040 Support/XOUT: R5.1; also elsewhere on the board
/RP2040 Support/~USB_BOOT: R1.2, S3.B
/USB_D+: J5.A6 (DP1), J5.B6 (DP2); also elsewhere on the board
/USB_D-: J5.A7 (DN1), J5.B7 (DN2); also elsewhere on the board
GND: C1.2, C2.2, C3.2, C4.2, C5.2, C17.2, J3.2, J4.2, J5.A1_B12 (GND), J5.A12_B1 (GND__1), J5.SH1 (SHIELD), J5.SH2 (SHIELD__1), J5.SH3 (SHIELD__2), J5.SH4 (SHIELD__3), R9.2, R10.2, S3.A, U1.1 (GND), U2.4 (GND), Y1.2, Y1.4; also elsewhere on the board
unnamed: C3.1, R5.2, Y1.3
unnamed: J5.A5 (CC1), SW1.2 (B)
unnamed: J5.B5 (CC2), SW1.5 (B)
unnamed: R8.2, SW1.1 (A)
unnamed: R10.1, SW1.3 (C)
unnamed: R9.1, SW1.4 (A)
unnamed: R7.2, SW1.6 (C)
VBUS: C1.1, J5.A4_B9 (VBUS), J5.A9_B4 (VBUS__1), R7.1, R8.1, U1.3 (VI); also elsewhere on the board

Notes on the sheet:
Power
Debug
Crystal
Flash
USB

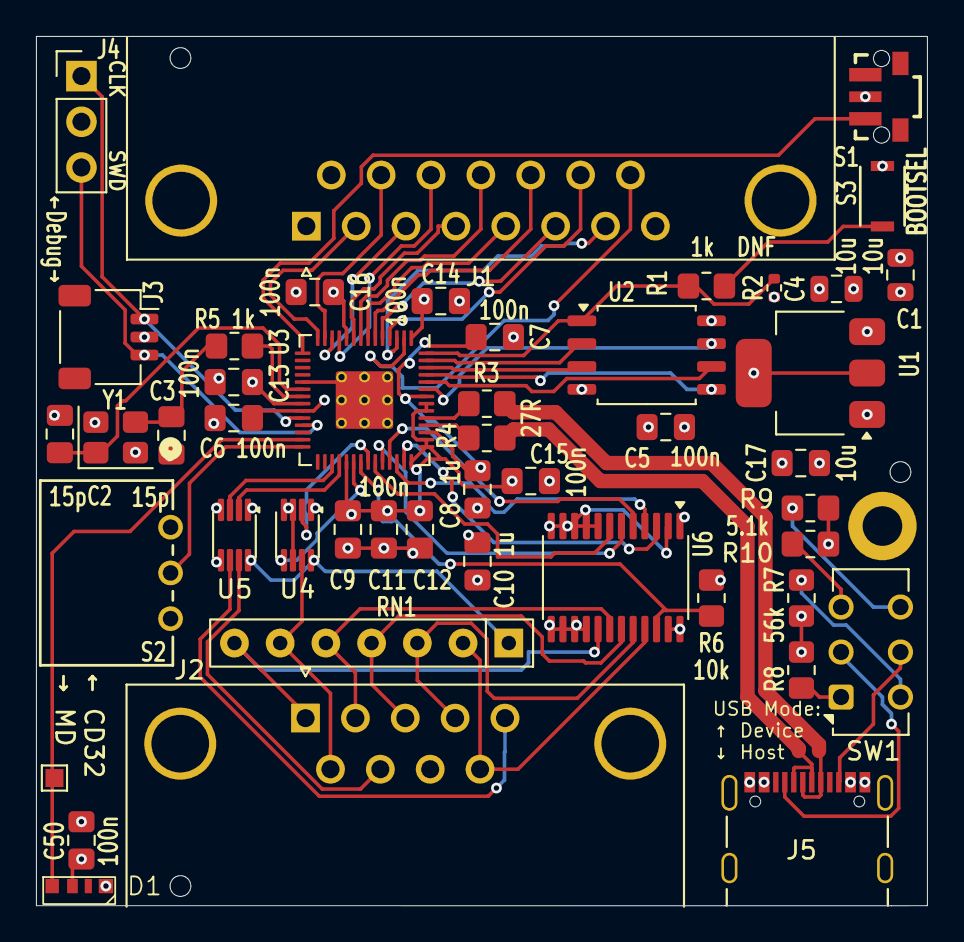
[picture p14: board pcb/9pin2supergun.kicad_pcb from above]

Board: 4 copper layers, 49.5 x 48.3 mm, 47 parts (1 on the bottom side), 59 nets.

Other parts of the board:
QR*****: QR code

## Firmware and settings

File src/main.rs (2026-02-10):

//! Reads a CD32 or Mega Drive gamepad and breaks it out into 7 individual active-low GPIO pins
#![no_std]
#![no_main]

use defmt::*;
use defmt_rtt as _;
use embassy_executor::Spawner;
use embassy_rp::bind_interrupts;
use embassy_rp::clocks::clk_sys_freq;
use embassy_rp::gpio::{Input, Level, Output, OutputOpenDrain, Pull};
use embassy_rp::peripherals::PIO0;
use embassy_rp::pio::program::pio_asm;
use embassy_rp::pio::{Direction as PioDirection, InterruptHandler, Pio, StateMachine};
use embassy_rp::pio_programs::ws2812::{PioWs2812, PioWs2812Program};
use embassy_rp::{Peri, Peripherals};
use embassy_time::Instant;
use fixed::traits::ToFixed;
use panic_probe as _;

use smart_leds::RGB8;

// If using a generic two-button controller, map A+B to be start
const MAP_GENERIC_AB_TO_START: bool = true;

// What bitmask should we look for to let us send the coin button in CD32 mode?
// The bits are as follows:
// Pause, LB, RB, Green, Yellow, Red, Blue
// Set to 0 to disable the feature.
// Default: Pause + Green
const CD32_COIN_BITMASK: u32 = 0b1001000;

bind_interrupts!(struct Irqs {
    PIO0_IRQ_0 => InterruptHandler<PIO0>;
});

// Board-specific config
#[cfg(not(feature = "pi_pico"))]
mod pcb;
#[cfg(feature = "pi_pico")]
mod pico;

#[cfg(not(feature = "pi_pico"))]
use pcb as board;
#[cfg(feature = "pi_pico")]
use pico as board;

use board::*;

type BoardPins = (
    Selector,
    PinSixDirection,
    Soe,
    InLatchPower,
    InPowerSelect,
    InFire1ClockBA,
    InUpZ,
    InDownY,
    InLeftGnd,
    InRightModeGnd,
    InFire2DataCStart,
    Led,
    FifteenPinOutput,
);

#[embassy_executor::main]
async fn main(_spawner: Spawner) {
    info!("Program start");
    let p = embassy_rp::init(Default::default());
    let (pins, pio0, _pio1, dma0, ..) = split_peripherals(p);

    let platform_pins = get_pins(pins);

    let (
        selector,
        pin_six_direction,
        shifter_oe,
        in_latch_power,
        in_power_select,
        in_fire1_clock_b_a,
        in_up_z,
        in_down_y,
        in_left_x_gnd,
        in_right_mode_gnd,
        in_fire2_data_c_start,
        led,
        outputs,
    ) = platform_pins;

    let Pio {
        mut common,
        sm0,
        sm1,
        ..
    } = Pio::new(pio0, Irqs);

    // Set up LED
    let led_prog = PioWs2812Program::new(&mut common);
    let mut ws: PioWs2812<'_, PIO0, 1, 1> = PioWs2812::new(&mut common, sm1, dma0, led, &led_prog);

    // Connect GPIO2 to GND for Mega Drive/generic 9-pin. high or floating for CD32.
    let selector = Input::new(selector, Pull::Up);
    let use_cd32 = selector.is_low();

    let pin_six_direction_set = Output::new(pin_six_direction, Level::Low);
    let shifter_oe_set = Output::new(shifter_oe, Level::Low);

    if use_cd32 {
        info!("CD32 mode");

        let colour: RGB8 = (255, 0, 0).into();
        ws.write(&[colour]).await;

        let power = Output::new(in_power_select, Level::Low);
        let up = Input::new(in_up_z, Pull::None);
        let down = Input::new(in_down_y, Pull::None);
        let left = Input::new(in_left_x_gnd, Pull::None);
        let right = Input::new(in_right_mode_gnd, Pull::None);
        let latch = common.make_pio_pin(in_latch_power);
        let clock = common.make_pio_pin(in_fire1_clock_b_a);
        let data = common.make_pio_pin(in_fire2_data_c_start);

        let cd32_pins = CD32Pins {
            power,
            up,
            down,
            left,
            right,
            latch,
            clock,
            data,
        };

        run_cd32_code(
            pin_six_direction_set,
            shifter_oe_set,
            cd32_pins,
            outputs,
            common,
            sm0,
            _spawner,
        );
    } else {
        info!("Mega Drive mode");

        let colour: RGB8 = (0, 0, 255).into();
        ws.write(&[colour]).await;

        // First set up all the pins
        let power = Output::new(in_latch_power, Level::Low);
        let select = common.make_pio_pin(in_power_select);
        let b_a = common.make_pio_pin(in_fire1_clock_b_a);
        let up_z = common.make_pio_pin(in_up_z);
        let down_y = common.make_pio_pin(in_down_y);
        let left_x_gnd = common.make_pio_pin(in_left_x_gnd);
        let right_mode_gnd = common.make_pio_pin(in_right_mode_gnd);
        let c_start = common.make_pio_pin(in_fire2_data_c_start);

        let md_pins = MDPins {
            power,
            select,
            b_a,
            up_z,
            down_y,
            left_x_gnd,
            right_mode_gnd,
            c_start,
        };

        // Then run the actual code
        run_md_code(
            pin_six_direction_set,
            shifter_oe_set,
            md_pins,
            outputs,
            common,
            sm0,
            ws,
            _spawner,
        );
    }
}

fn run_cd32_code(
    pin_six_direction: Output<'static>,
    shifter_oe: Output<'static>,
    cd32_pins: CD32Pins,
    outputs: FifteenPinOutput,
    mut pio: embassy_rp::pio::Common<'static, PIO0>,
    mut sm0: StateMachine<'static, PIO0, 0>,
    spawner: Spawner,
) {
    let cd32_pins = setup_state_machine_cd32(&mut pio, &mut sm0, cd32_pins);

    let _ = spawner.spawn(read_cd32_loop(
        pin_six_direction,
        shifter_oe,
        sm0,
        cd32_pins,
        outputs,
    ));
}

fn setup_state_machine_cd32<'d>(
    pio: &mut embassy_rp::pio::Common<'d, PIO0>,
    sm0: &mut StateMachine<'d, PIO0, 0>,
    cd32_pins: CD32Pins,
) -> CD32Pins {
    let pio_multiplier = clk_sys_freq() / 140_000;
    info!("PIO multiplier is {}", pio_multiplier);

    let (power, up, down, left, right, set_pin, side_set_pin, in_pin) = cd32_pins.destructure();

    let read_cd32 = pio_asm!(
        ".side_set 1 opt",
        "begin:",
        "    set pins, 0    side 0 [2]",
        "    in  pins, 1    side 0 [1]", // Blue button (5)
        "    nop            side 1",
        "    in  pins, 1    side 0 [3]", // Red (4)
        "    nop            side 1",
        "    in  pins, 1    side 0 [3]", // Yellow (2)
        "    nop            side 1",
        "    in  pins, 1    side 0 [3]", // Green (1)
        "    nop            side 1",
        "    in  pins, 1    side 0 [3]", // Right front (6)
        "    nop            side 1",
        "    in  pins, 1    side 0 [3]", // Left front (3)
        "    nop            side 1",
        "    in  pins, 1    side 0 [3]", // Pause (Start)
        "    push noblock          [2]", // Move to the RX FIFO so the main code can deal with it
        "    set x, 31",
        "    nop                   [7]",
        "    nop                   [7]",
        "    nop                   [7]",
        "    nop                   [3]",
        "    set pins, 1    side 1 [3]",
        "wait_loop:",
        "    nop                   [7]",
        "    nop                   [7]",
        "    nop                   [7]",
        "    nop                   [3]",
        "    jmp x-- wait_loop",
        "    jmp begin",
    );

    let mut cfg = embassy_rp::pio::Config::default();
    cfg.use_program(&pio.load_program(&read_cd32.program), &[&side_set_pin]);
    cfg.set_set_pins(&[&set_pin]);
    cfg.set_in_pins(&[&in_pin]);
    cfg.clock_divider = pio_multiplier.to_fixed();
    //cfg.shift_in.auto_fill = true;
    //cfg.shift_in.direction = embassy_rp::pio::ShiftDirection::Left;

    sm0.set_pin_dirs(PioDirection::Out, &[&set_pin, &side_set_pin]);
    sm0.set_pin_dirs(PioDirection::In, &[&in_pin]);

    sm0.set_config(&cfg);
    sm0.set_enable(false);

    CD32Pins {
        power,
        up,
        down,
        left,
        right,
        latch: set_pin,
        clock: side_set_pin,
        data: in_pin,
    }
}

#[embassy_executor::task]
async fn read_cd32_loop(
    mut pin_six_direction: Output<'static>,
    mut shifter_oe: Output<'static>,
    mut sm0: StateMachine<'static, PIO0, 0>,
    cd32_pins: CD32Pins,
    outputs: FifteenPinOutput,
) {
    let (mut power, up, down, left, right, _, _, _) = cd32_pins.destructure();

    // Pin six is going out
    pin_six_direction.set_high();

    // Enable the output on the level shifter
    shifter_oe.set_low();

    // Enable the power to the controller
    power.set_high();

    // There absolutely must be a better way of doing this, but this works.
    let (
        pin_start,
        pin_coin,
        pin_b1,
        pin_b2,
        pin_b3,
        pin_b4,
        pin_b5,
        pin_b6,
        pin_up,
        pin_down,
        pin_left,
        pin_right,
    ) = outputs.destructure();
    // Initialise all the pins
    let mut pin_start = OutputOpenDrain::new(pin_start, Level::High);
    let mut pin_coin = OutputOpenDrain::new(pin_coin, Level::High);
    let mut pin_b1 = OutputOpenDrain::new(pin_b1, Level::High);
    let mut pin_b2 = OutputOpenDrain::new(pin_b2, Level::High);
    let mut pin_b3 = OutputOpenDrain::new(pin_b3, Level::High);
    let mut pin_b4 = OutputOpenDrain::new(pin_b4, Level::High);
    let mut pin_b5 = OutputOpenDrain::new(pin_b5, Level::High);
    let mut pin_b6 = OutputOpenDrain::new(pin_b6, Level::High);
    let mut pin_up = OutputOpenDrain::new(pin_up, Level::High);
    let mut pin_down = OutputOpenDrain::new(pin_down, Level::High);
    let mut pin_left = OutputOpenDrain::new(pin_left, Level::High);
    let mut pin_right = OutputOpenDrain::new(pin_right, Level::High);

    sm0.set_enable(true);

    loop {
        let rx = sm0.rx().wait_pull().await;
        // We only care about 7 bits of the 32 bits, make it a bit easier to deal with
        let mut our_data = rx >> 25;

        // Set CD32_COIN_BITMASK to customise what this matches
        pin_coin.set_level(get_pin_state(our_data & CD32_COIN_BITMASK));

        // If we've got the chord for the coin button, get rid of the component buttons so they don't fire as well
        if (our_data & CD32_COIN_BITMASK) == 0 {
            our_data |= CD32_COIN_BITMASK;
        }

        pin_start.set_level(get_pin_state(our_data & 0b1000000));
        pin_b1.set_level(get_pin_state(our_data & 0b0001000));
        pin_b2.set_level(get_pin_state(our_data & 0b0000100));
        pin_b3.set_level(get_pin_state(our_data & 0b0100000));
        pin_b4.set_level(get_pin_state(our_data & 0b0000010));
        pin_b5.set_level(get_pin_state(our_data & 0b0000001));
        pin_b6.set_level(get_pin_state(our_data & 0b0010000));

        if our_data != 127 {
            debug!("Got bits: {:#09b}", our_data);
            debug!("            S361245");
            debug!(
                "Buttons: 1 {} 2 {} 3 {} 4 {} 5 {} 6 {} start {} coin {}",
                pin_b1.is_set_high(),
                pin_b2.is_set_high(),
                pin_b3.is_set_high(),
                pin_b4.is_set_high(),
                pin_b5.is_set_high(),
                pin_b6.is_set_high(),
                pin_start.is_set_high(),
                pin_coin.is_set_high(),
            );
        }

        pin_up.set_level(Level::from(up.is_high()));
        pin_down.set_level(Level::from(down.is_high()));
        pin_left.set_level(Level::from(left.is_high()));
        pin_right.set_level(Level::from(right.is_high()));

        debug!(
            "Up: {}, Down: {}, Left: {}, Right: {}",
            pin_up.is_set_high(),
            pin_down.is_set_high(),
            pin_left.is_set_high(),
            pin_right.is_set_high(),
        );
    }
}

#[allow(clippy::too_many_arguments)]
fn run_md_code(
    pin_six_direction: Output<'static>,
    shifter_oe: Output<'static>,
    md_pins: MDPins,
    outputs: FifteenPinOutput,
    mut pio: embassy_rp::pio::Common<'static, PIO0>,
    mut sm0: StateMachine<'static, PIO0, 0>,
    ws: PioWs2812<'static, PIO0, 1, 1>,
    spawner: Spawner,
) {
    let md_pins = setup_state_machine_md(&mut pio, &mut sm0, md_pins);

    let _ = spawner.spawn(read_md_loop(
        pin_six_direction,
        shifter_oe,
        sm0,
        md_pins,
        outputs,
        ws,
    ));
}

fn setup_state_machine_md<'d>(
    pio: &mut embassy_rp::pio::Common<'d, PIO0>,
    sm0: &mut StateMachine<'d, PIO0, 0>,
    md_pins: MDPins,
) -> MDPins {
    let pio_multiplier = clk_sys_freq() / 140_000;

    info!("PIO multiplier is {}", pio_multiplier);

    let (power, side_set_pin, b_a, up_z, down_y, left_x_gnd, right_mode_gnd, c_start) =
        md_pins.destructure();

    let read_md = pio_asm!(
    ".side_set 1",
    ".wrap_target",
    "    in  pins, 6        side 0", // Start/A/GND/GND
    "    in  pins, 6        side 1", // Normal
    "    nop                side 0",
    "    nop                side 1", // Same as first IN
    "    nop                side 0", // Same as second IN
    "    in  pins, 6        side 1", // All directions GND if 6-button
    "    in  pins, 6        side 0", // Mode/X/Y/Z
    "    push noblock       side 1", // Push off to FIFO
    "    set x, 31          side 1", // These delays get it down to around 140Hz polling
    "    nop           [6]  side 1", // This has been verified via oscilloscope rather than maths
    "    nop           [6]  side 1",
    "    nop           [6]  side 1",
    "    nop           [6]  side 1",
    "    nop           [6]  side 1",
    "    nop           [2]  side 1",
    "wait_loop:"                     // 30 cycles each iteration of this loop.
    "    nop           [6]  side 1",
    "    nop           [6]  side 1",
    "    nop           [6]  side 1",
    "    nop           [6]  side 1",
    "    nop                side 1",
    "    jmp x-- wait_loop  side 1",
    ".wrap",
    );

    let mut cfg = embassy_rp::pio::Config::default();
    cfg.use_program(&pio.load_program(&read_md.program), &[&side_set_pin]);
    cfg.set_in_pins(&[&b_a, &up_z, &down_y, &left_x_gnd, &right_mode_gnd, &c_start]);
    cfg.clock_divider = pio_multiplier.to_fixed();

    sm0.set_pin_dirs(PioDirection::Out, &[&side_set_pin]);
    sm0.set_pin_dirs(
        PioDirection::In,
        &[&b_a, &up_z, &down_y, &left_x_gnd, &right_mode_gnd, &c_start],
    );

    sm0.set_config(&cfg);
    sm0.set_enable(false);

    MDPins {
        power,
        select: side_set_pin,
        b_a,
        up_z,
        down_y,
        left_x_gnd,
        right_mode_gnd,
        c_start,
    }
}

#[embassy_executor::task]
async fn read_md_loop(
    mut pin_six_direction: Output<'static>,
    mut shifter_oe: Output<'static>,
    mut sm0: StateMachine<'static, PIO0, 0>,
    md_pins: MDPins,
    outputs: FifteenPinOutput,
    mut ws: PioWs2812<'static, PIO0, 1, 1>,
) -> ! {
    let (mut plus_five_volts, _, _, _, _, _, _, _) = md_pins.destructure();
    plus_five_volts.set_high();

    pin_six_direction.set_low();
    // Enable the output on the level shifter
    shifter_oe.set_low();

    // There absolutely must be a better way of doing this, but this works.
    let (
        pin_start,
        pin_coin,
        pin_b1,
        pin_b2,
        pin_b3,
        pin_b4,
        pin_b5,
        pin_b6,
        pin_up,
        pin_down,
        pin_left,
        pin_right,
    ) = outputs.destructure();

    // Initialise all the pins
    let mut pin_start = OutputOpenDrain::new(pin_start, Level::High);
    let mut pin_coin = OutputOpenDrain::new(pin_coin, Level::High);
    let mut pin_b1 = OutputOpenDrain::new(pin_b1, Level::High);
    let mut pin_b2 = OutputOpenDrain::new(pin_b2, Level::High);
    let mut pin_b3 = OutputOpenDrain::new(pin_b3, Level::High);
    let mut pin_b4 = OutputOpenDrain::new(pin_b4, Level::High);
    let mut pin_b5 = OutputOpenDrain::new(pin_b5, Level::High);
    let mut pin_b6 = OutputOpenDrain::new(pin_b6, Level::High);
    let mut pin_up = OutputOpenDrain::new(pin_up, Level::High);
    let mut pin_down = OutputOpenDrain::new(pin_down, Level::High);
    let mut pin_left = OutputOpenDrain::new(pin_left, Level::High);
    let mut pin_right = OutputOpenDrain::new(pin_right, Level::High);

    sm0.set_enable(true);

    let mut swap_rows = false;
    // Whilst theoretically using 0 for a null value might lead to clashes, it's irrelevant because the next polling loop will fix it
    let mut mode_pressed_time = 0;

    loop {
        let rx = sm0.rx().wait_pull().await;
        // We only care about 24 bits of the 32 bits, make it a bit easier to deal with
        let our_data = rx >> 8;

        if our_data & 0b000000011000011000000000 == 0 {
            debug!("Mega Drive");
            // Mega Drive controller
            // Three button Mega Drive controller buttons:
            // Data: 0bxxxxxxxxxxxxSGGDUACRLDUA
            pin_start.set_level(get_pin_state(our_data & 0b100000000000));
            pin_down.set_level(get_pin_state(our_data & 0b000100000000));
            pin_up.set_level(get_pin_state(our_data & 0b000010000000));

            if !swap_rows {
                pin_b1.set_level(get_pin_state(our_data & 0b000001000000));
                pin_b2.set_level(get_pin_state(our_data & 0b000000000001));
                pin_b3.set_level(get_pin_state(our_data & 0b000000100000));
            }
            pin_right.set_level(get_pin_state(our_data & 0b000000010000));
            pin_left.set_level(get_pin_state(our_data & 0b000000001000));

            if our_data & 0b000000011110000000000000 == 0 {
                // 6 button controller
                // Extra buttons: 0bxMXYZx
                let six_button_data = our_data >> 18;
                debug!("Got a 6 button");
                if swap_rows {
                    pin_b1.set_level(get_pin_state(six_button_data & 0b001000));
                    pin_b2.set_level(get_pin_state(six_button_data & 0b000100));
                    pin_b3.set_level(get_pin_state(six_button_data & 0b000010));
                    pin_b4.set_level(get_pin_state(our_data & 0b000001000000));
                    pin_b5.set_level(get_pin_state(our_data & 0b000000000001));
                    pin_b6.set_level(get_pin_state(our_data & 0b000000100000));
                } else {
                    pin_b4.set_level(get_pin_state(six_button_data & 0b001000));
                    pin_b5.set_level(get_pin_state(six_button_data & 0b000100));
                    pin_b6.set_level(get_pin_state(six_button_data & 0b000010));
                }

                pin_coin.set_level(get_pin_state(six_button_data & 0b010000));

                // Handle swapping around A/B/C and X/Y/Z
                if six_button_data & 0b010000 == 0 {
                    if mode_pressed_time == 0 {
                        mode_pressed_time = Instant::now().as_millis();
                    } else {
                        // Hold for three seconds to invert
                        if Instant::now().as_millis() - mode_pressed_time > 1_000 * 3 {
                            swap_rows = !swap_rows;
                            mode_pressed_time = 0;
                            debug!("Swapping rows, inverted now: {}", swap_rows);
                        }
                        let mut colour: RGB8 = (0, 0, 255).into();

                        if swap_rows {
                            colour = (255, 255, 0).into();
                        }

                        ws.write(&[colour]).await;
                    }
                } else {
                    mode_pressed_time = 0;
                }
            } else {
                // Tidy up buttons we don't have
                pin_b4.set_level(Level::High);
                pin_b5.set_level(Level::High);
                pin_b6.set_level(Level::High);

                // There are no rows to swap
                swap_rows = false;
                mode_pressed_time = 0;
            }
        } else {
            // Generic controller
            // 0b2RLDU1
            if MAP_GENERIC_AB_TO_START {
                pin_start.set_level(get_pin_state(our_data & 0b100001));
            } else {
                pin_start.set_level(Level::High);
            }

            pin_b1.set_level(get_pin_state(our_data & 0b000001));

            pin_down.set_level(get_pin_state(our_data & 0b000100));
            pin_up.set_level(get_pin_state(our_data & 0b000010));
            pin_right.set_level(get_pin_state(our_data & 0b010000));
            pin_left.set_level(get_pin_state(our_data & 0b001000));

            // Tidy up missing buttons
            pin_b3.set_level(Level::High);
            pin_b4.set_level(Level::High);
            pin_b5.set_level(Level::High);
            pin_b6.set_level(Level::High);
            pin_coin.set_level(Level::High)
        }

        debug!("Got bits: {:#026b}", our_data);
    }
}

// Let's avoid having to have all this everywhere
struct FifteenPinOutput {
    output_start: OutputStart,
    output_coin: OutputCoin,
    output_b1: OutputB1,
    output_b2: OutputB2,
    output_b3: OutputB3,
    output_b4: OutputB4,
    output_b5: OutputB5,
    output_b6: OutputB6,
    output_up: OutputUp,
    output_down: OutputDown,
    output_left: OutputLeft,
    output_right: OutputRight,
}

impl FifteenPinOutput {
    fn destructure(
        self,
    ) -> (
        OutputStart,
        OutputCoin,
        OutputB1,
        OutputB2,
        OutputB3,
        OutputB4,
        OutputB5,
        OutputB6,
        OutputUp,
        OutputDown,
        OutputLeft,
        OutputRight,
    ) {
        (
            self.output_start,
            self.output_coin,
            self.output_b1,
            self.output_b2,
            self.output_b3,
            self.output_b4,
            self.output_b5,
            self.output_b6,
            self.output_up,
            self.output_down,
            self.output_left,
            self.output_right,
        )
    }
}

// Turn a positive bitmask result into Level::High and anything else into Level::Low
fn get_pin_state(result: u32) -> Level {
    Level::from(result > 0)
}
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

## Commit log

2025-11-17 Support multiple pin sets, allowing for building for a Pi Pico or my PCB. This was a lot more work than it sounds.
2025-11-18 Add PCB
    [9pin2supergun.kicad_pcb, 9pin2supergun.kicad_sch, project_components.kicad_sch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]
2025-11-18 Ignore some PCB files
2025-11-18 Add kicad rendering, hopefully working
2025-11-18 Render schematics and gerbers
    [bom.csv, pcb.step]
2025-11-18 Update README having published the PCB
2025-11-19 Disable current clippy complexity warnings - I don't think they're in places where fixing them would actually help all that much.
    [main.rs]
2025-11-19 I do actually know what this pin does
2025-11-19 Update the schematic to properly use hierarchical sheets, update the PCB to match, tidy up some weirdnesses (button with a "U" refdes, both S and SW refdes, etc)
    [9pin2supergun.kicad_pcb, 9pin2supergun.kicad_sch, project_components.kicad_sch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]
2025-11-20 Add README for PCB, update automation, hopefully correctly
2025-12-04 Add a reference Pico design
    [9pin2supergun.kicad_pcb, 9pin2supergun.kicad_sch]
2025-12-04 Update KiCad rendering job to indicate it's only for the main PCB
2026-01-07 Missed out the track from /OE to the actual chips that use it, which is unhelpful.
    [9pin2supergun.kicad_pcb]
2026-01-07 And somehow the 3.3v also got disconnected there?
    [9pin2supergun.kicad_pcb]
2026-01-07 And the DRC didn't tell me that coin wasn't connected either
    [9pin2supergun.kicad_pcb]
2026-01-10 It's not just for a Pi Pico any more
2026-02-05 Update PCB to v1.1: * Update level shifting to a component that actually supports 5V * Make both D-Sub connectors the same size in terms of pin offset (added bonus of making the board smaller) * Upda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
    [9pin2supergun.kicad_pcb, 9pin2supergun.kicad_sch, project_components.kicad_sch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]
2026-02-06 Update Pico reference design to use different level shifters
    [9pin2supergun.kicad_pcb, 9pin2supergun.kicad_sch]
2026-02-06 Add note about changing a shifter for PCBA
2026-02-10 Replace framework with embassy-rp for future benefits
    [main.rs]
